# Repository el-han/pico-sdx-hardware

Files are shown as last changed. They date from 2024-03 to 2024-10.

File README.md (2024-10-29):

# Pico SDX

Pico SDX is a Software Defined HF Transceiver.

## Related Projects

- [uSDX](https://github.com/threeme3/usdx): ATmega 328P based SSB Transceiver. Large Arduino source file, no hardware sources, only schematics
- [(tr)uSDX](https://dl2man.de/): Implementation of uSDX by DL2MAN. No hardware sources, only schematics
- [uSDX-x](https://github.com/KD9PDP/uSDX-x): uSDX implementation with KiCAD hardware sources and JLCPCB friendly manufacturing data. ATmega328P based and compatible to uSDX. **Looks like a good starting point**
- [uSDR-pico](https://github.com/ArjanteMarvelde/uSDR-pico): RP2040 based SSB Transceiver. Highly experimental according to author. Pico SDK based Firmware, Eagle hardware sources. **Looks like a good starting point**
- [Blueberry SDR](http://www.andreadrian.de/sdr/Blueberry_SDR_schematics.html) experiments with different designs and components
- [YU1MLs SDRs](https://web.archive.org/web/20200227193146/http://yu1lm.qrpradio.com/sdr%20rx%20yu1lm.htm) many RX, TX and TRX designs
- [Teensy SDR](https://www.pjrc.com/convolution-software-defined-radio/) Teensy based sdr with waterfall diagram

## Related resources

- [Barbaros Aşuroğlu](https://antrak.org.tr/author/barbarosasuroglu/) has built an own uSDX implementation and many other projects.
- [QRP labs](https://www.qrp-labs.com/lpfkit.html) sells low pass and band pass filter modules for all HF bands
- [QRP labs](https://www.qrp-labs.com/synth/ms5351m.html) comparison between the clock generators Si5351A (Silicon labs) and MS5351M (Relmon) regarding usage in SDRs
- [Calculate your locator](https://dxcluster.ha8tks.hu/hamgeocoding/)

## technical background

- [Dan Tayloe](https://www.norcalqrp.org/files/Tayloe_mixer_x3a.pdf) brief description of the operation of quadratur mixers
- Gerald Youngbloods QEX articles [1](https://www.arrl.org/files/file/Technology/tis/info/pdf/020708qex013.pdf), [2](https://www.arrl.org/files/file/Technology/tis/info/pdf/020910qex010.pdf), [3](https://www.arrl.org/files/file/Technology/tis/info/pdf/021112qex027.pdf) and [4](http://www.arrl.org/files/file/Technology/tis/info/pdf/030304qex020.pdf) very good, detailed and comprehensive description of SDR projects for ham radio operators and additional [ARRL SDR](http://www.arrl.org/software-defined-radio) resources
- Walla Walla University projects: [Paper](http://fweb.wallawalla.edu/~frohro/ClassHandouts/Electronics/A%20Comparison%20of%20Affordable,%20Self-Assembled%20%20Software-Defined%20Radio%20Receivers%20Using%20Quadrature%20Sampling%20Down-Conversion.pdf), [Talk](https://www.youtube.com/watch?v=UoL1Qzaw2H0&t=217s),[Jordyn Watkins Wiki](https://github.com/greenjacketgirl/SDR_Receiver/wiki), [Caleb Froelichs Wiki](https://github.com/froeca/Software-Defined-Radio/), [Konrad MacClure](https://github.com/KonradMcClure/SDR_Receiver) and [SMD Version by Caleb Nelson](https://github.com/Dizzerin/Software-Defined-Radio)with detailed explanations, simulations, design decisions and tests
- [Burkhard Kainkas](https://www.b-kainka.de/iqrx.htm) experiments with iq mixers
- [devttys0](https://www.youtube.com/watch?v=JuuKF1RFvBM) video on explanations of the function of the tayloe mixer
- [w2aew](https://www.youtube.com/watch?v=Mm7WfVzr1ao) video on RF-mixer basics
- [BPF design for HF-Tranceiver](https://www.arrl.org/files/file/Technology/tis/info/pdf/8809017.pdf)
- [devttys0](https://www.youtube.com/watch?v=1sq8Cvju2Oo) video on practical filter design and construction

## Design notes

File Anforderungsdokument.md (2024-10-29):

Anforderungen Pico SDX
======================

Das soll es haben
-----------------

- Sendeleistung 20 W
- Betriebsarten:
    - SSB
    - WSPR
    - (CW)
- Bänder:
    - Kurzwelle
    - Unterstes Band: 80 Meter
    - Oberstes Band: 10 Meter
    - 4 bis 8 Bänder
- Stromversorgung:
    - Lithium-Akku (Rundzellen oder Modellbauakkus)
    - Ladeschaltung
    - USB-PD oder Rundstecker?
- Weitgehend tragbar (mindestens im Rucksack)
- Open Source Hardware, Firmware und Software
- PCB-Design in KiCAD

Damit würde ich beginnen, würde aber auch davon abweichen:
----------------------------------------------------------

- Microcontroller: RP2040
- Sprache:
    - Firmware: Micropython / Circuitpython
    - PC-Software: Python
- Antennenanschluss: BNC 50 Ohm
- Möglichst viele SMD-Komponenten / hybride Footprints
- Möglichst viele Komponenten aus dem  JLC Bestückungskatalog
- I2S Mikrophon und Lautsprecherverstärker
- Modularer Aufbau:
    - Stromversorgung
    - Filter
    - HF Platine
    - Digitalteil
    - Audioteil / PC-Verbindung
    - User Interface (Display, Schalter)

Offene Fragen:
--------------

* Gibt es gängige PC-Anwendungsschnittlstellen (USB-Soundkarte, UART-Protokoll, SDR-Treiber, ...)?
* Ist ein Wasserfalldiagramm umsetzbar?

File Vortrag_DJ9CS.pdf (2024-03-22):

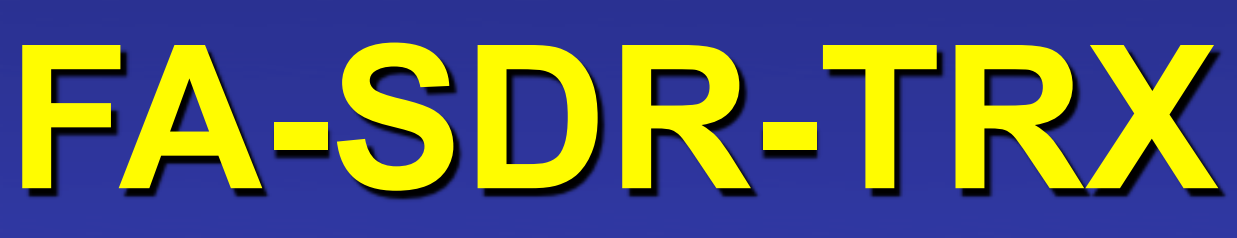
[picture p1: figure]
FA-SDR-TRX

## Einführung

## Software Defined Radio

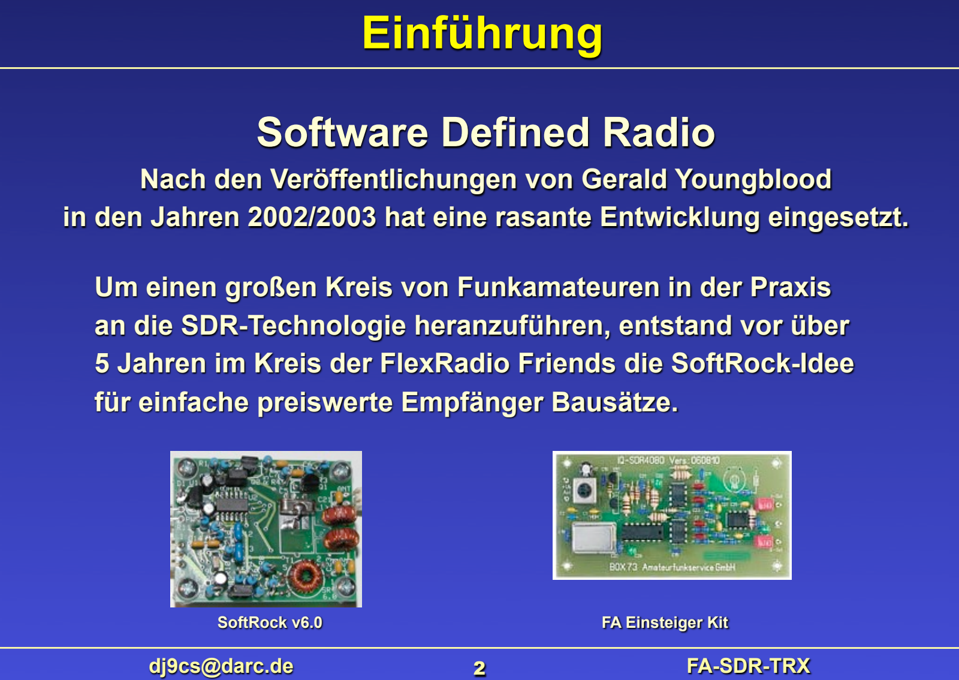
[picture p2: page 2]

dj9cs@darc.de | F 2 | A-SDR-TRX

Nach den Veröffentlichungen von Gerald Youngblood in den Jahren 2002/2003 hat eine rasante Entwicklung eingesetzt.

Um einen großen Kreis von Funkamateuren in der Praxis
an die SDR-Technologie heranzuführen, entstand vor über

### 5 Jahren im Kreis der FlexRadio Friends die SoftRock-Idee

für einfache preiswerte Empfänger Bausätze.

SoftRock v6.0 | FA Einsteiger Kit

## Einführung

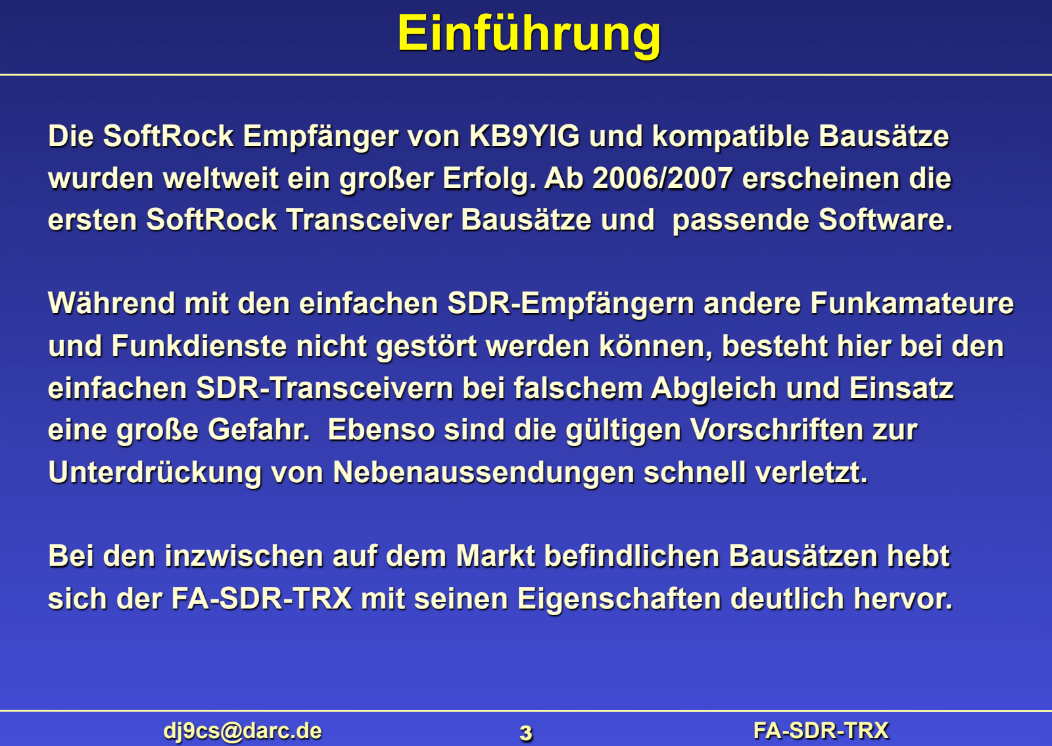
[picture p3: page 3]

dj9cs@darc.de | F 3 | A-SDR-TRX

Die SoftRock Empfänger von KB9YIG und kompatible Bausätze wurden weltweit ein großer Erfolg. Ab 2006/2007 erscheinen die ersten SoftRock Transceiver Bausätze und passende Software.

Während mit den einfachen SDR-Empfängern andere Funkamateure und Funkdienste nicht gestört werden können, besteht hier bei den einfachen SDR-Transceivern bei falschem Abgleich und Einsatz eine große Gefahr. Ebenso sind die gültigen Vorschriften zur Unterdrückung von Nebenaussendungen schnell verletzt.

Bei den inzwischen auf dem Markt befindlichen Bausätzen hebt sich der FA-SDR-TRX mit seinen Eigenschaften deutlich hervor.

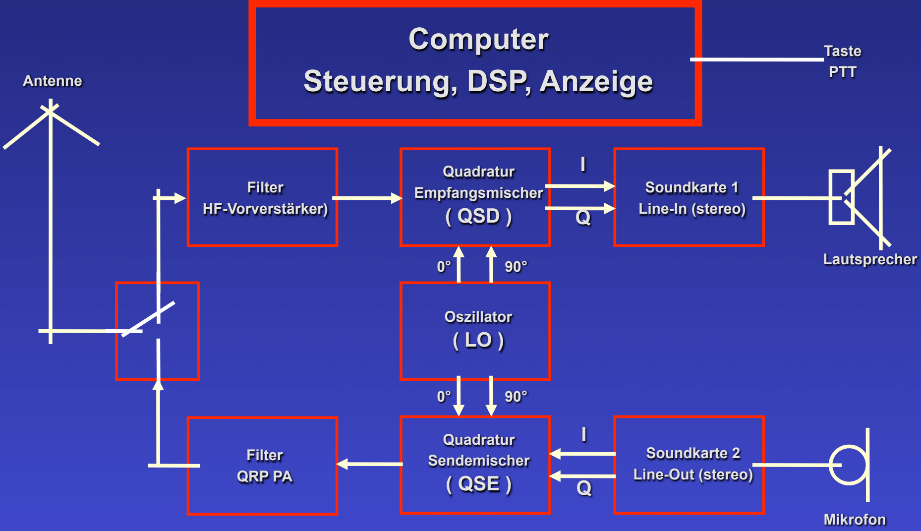
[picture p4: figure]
Computer Steuerung, DSP, Anzeige; Quadratur Empfangsmischer ( QSD ); Quadratur Sendemischer ( QSE ); Oszillator ( LO ); Soundkarte 1 Line-In (stereo); Soundkarte 2 Line-Out (stereo); Filter HF-Vorverstärker); Filter QRP PA; Mikrofon; Lautsprecher; Antenne; Taste PTT

dj9cs@darc.de | F 4 | A-SDR-TRX

dj9cs@darc.de | F 5 | A-SDR-TRX

Im Folgenden wird der FA-SDR-TRX mit seinen technischen Details dargestellt und aufgezeigt,

einem ausgezeichnetem Ergebnis geführt hat.

## Übersichtsschaltbild des FA- SDR-Transceivers

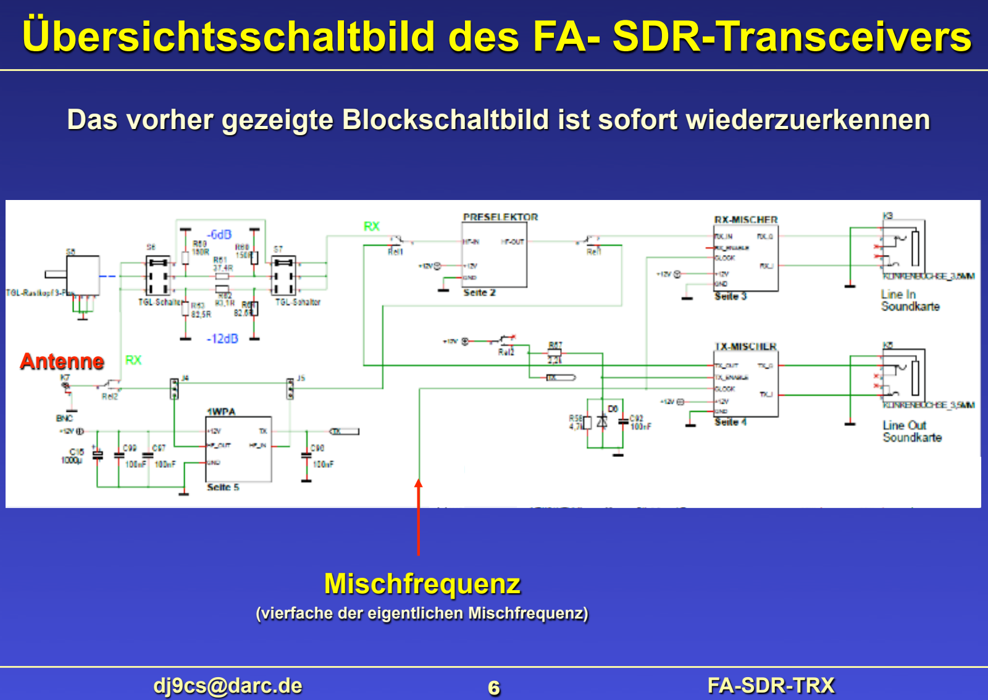
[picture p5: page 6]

dj9cs@darc.de | F 6 | A-SDR-TRX

Mischfrequenz

(vierfache der eigentlichen Mischfrequenz)

Antenne

Das vorher gezeigte Blockschaltbild ist sofort wiederzuerkennen

dj9cs@darc.de | F 7 | A-SDR-TRX

Den Kern der Osillatorbaugruppe bildet der Si570 von SiLabs. Es handelt sich um einen DSPLL-Chip mit herausragenden Eigenschaften. Bei DSPLL handelt es sich um ein Patent von Silicon Labs in den USA.
Mit dem Si570 werden Signale hoher Reinheit und Stabilität erzielt, vergleichbar mit Quarzoszillatoren.
Der Si570 stellt inzwischen einen Quasi-Standard bei allen SDR-Bausätzen dar. Hier im FA-SDR-TRX wird der FA-SY 1 eingesetzt.

## FA-SY im FA-SDR-TRX

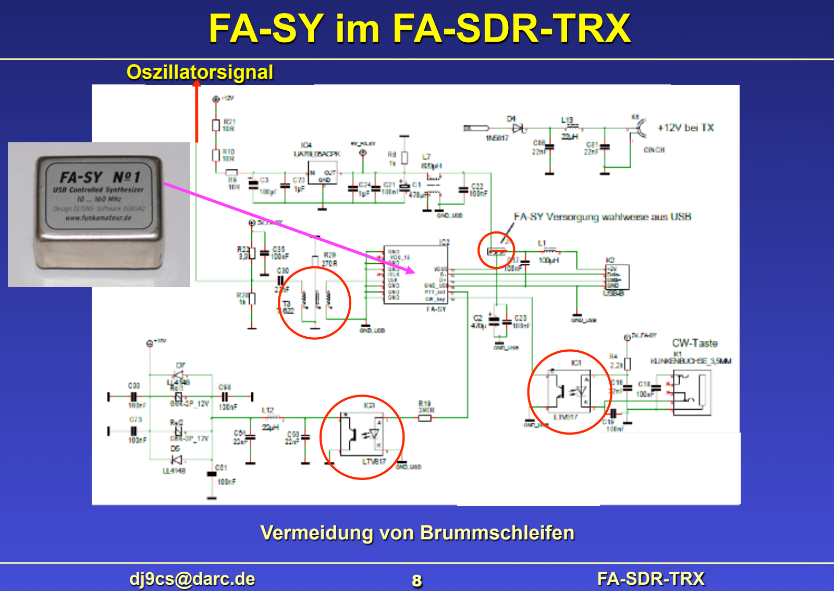
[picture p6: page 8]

dj9cs@darc.de | F 8 | A-SDR-TRX

Oszillatorsignal

Vermeidung von Brummschleifen

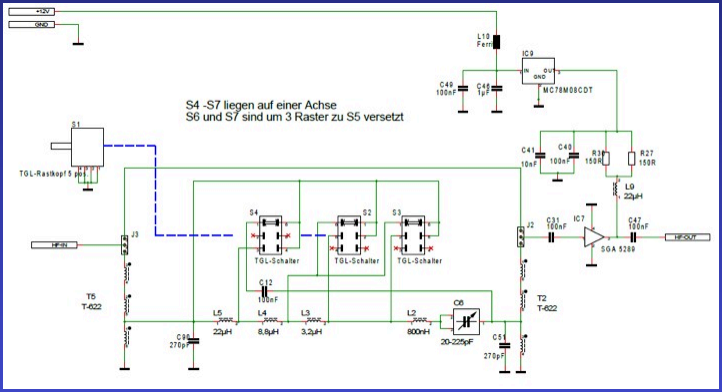
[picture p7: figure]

dj9cs@darc.de | F 9 | A-SDR-TRX

## Preselektor

dj9cs@darc.de | F 10 | A-SDR-TRX

Die Quadraturmischer im Empfänger und Sender sind die Kernbaugruppen im Konzept der einfachen SDR-Transceiver.

Die Empfängerdaten wie
- Empfindlichkeit (MDS @500Hz Bandbreite)
- Seitenbandunterdrückung
- nutzbarer Frequenzbereich
werden durch die Schaltkreise im Mischer wesentlich bestimmt. In
einem Experimentalaufbau wurden die Schalter-ICs FST3253, MAX4544, 74HC4066, MAX4614 und 74LVC4066 untersucht.
Mit den 74LVC4066 werden die besten Ergebnisse erreicht. Bis ins 2m-Band sind sie bei Subharmonischenmischung einsetzbar. Eine geringe Streuung in den Daten erlaubt zudem eine hohe Nachbausicherheit.

## Empfängermischer (QSD)

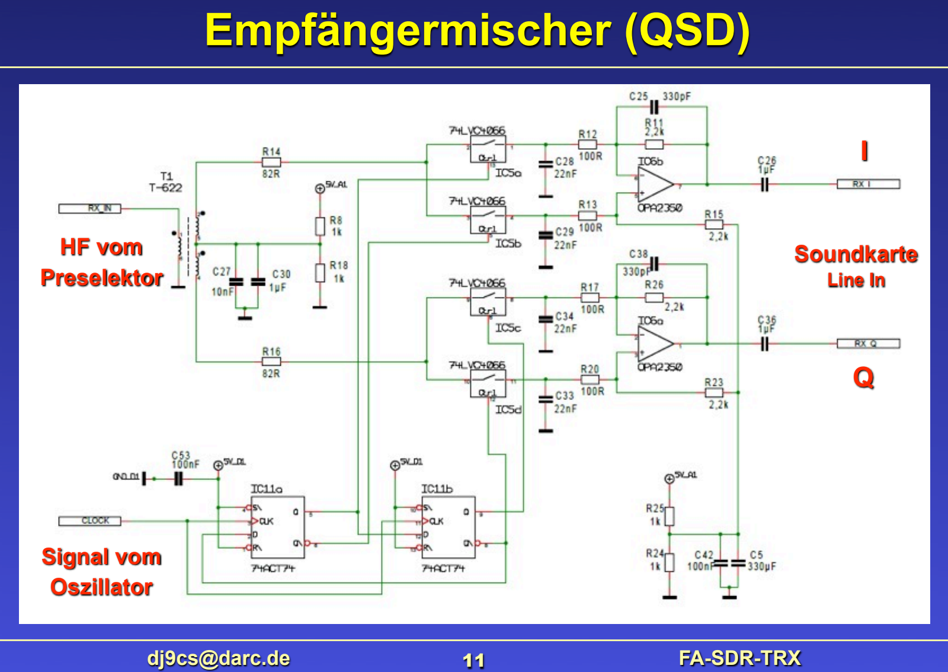
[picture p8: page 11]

dj9cs@darc.de | F 11 | A-SDR-TRX

I

Q

Soundkarte
Line In

HF vom
Preselektor

Signal vom
Oszillator

## Empfängermischer

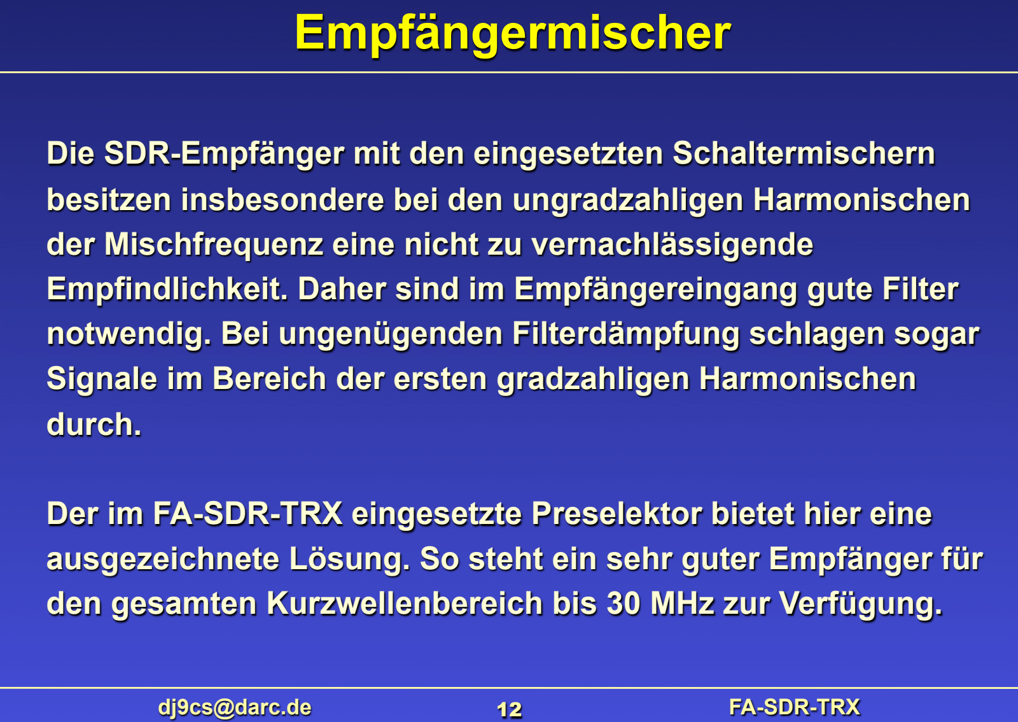
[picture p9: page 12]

dj9cs@darc.de | F 12 | A-SDR-TRX

Die SDR-Empfänger mit den eingesetzten Schaltermischern besitzen insbesondere bei den ungradzahligen Harmonischen der Mischfrequenz eine nicht zu vernachlässigende Empfindlichkeit. Daher sind im Empfängereingang gute Filter notwendig. Bei ungenügenden Filterdämpfung schlagen sogar Signale im Bereich der ersten gradzahligen Harmonischen durch.

Der im FA-SDR-TRX eingesetzte Preselektor bietet hier eine ausgezeichnete Lösung. So steht ein sehr guter Empfänger für den gesamten Kurzwellenbereich bis 30 MHz zur Verfügung.

dj9cs@darc.de | F 13 | A-SDR-TRX

Für den Sendebetrieb werden die I/Q-Signale im PC in der DSP berechnet und über die Soundkarte als analoge Signale dem Sendermischer zugeführt.

## Sendermischer (QSE)

dj9cs@darc.de | F 14 | A-SDR-TRX

Soundkarte
Line Out

I

Q

QRP PA
über
Filter

Signal vom
Oszillator

Trägerunterdrückung

Spiegelfrequenzunterdrückung

## Sendermischer

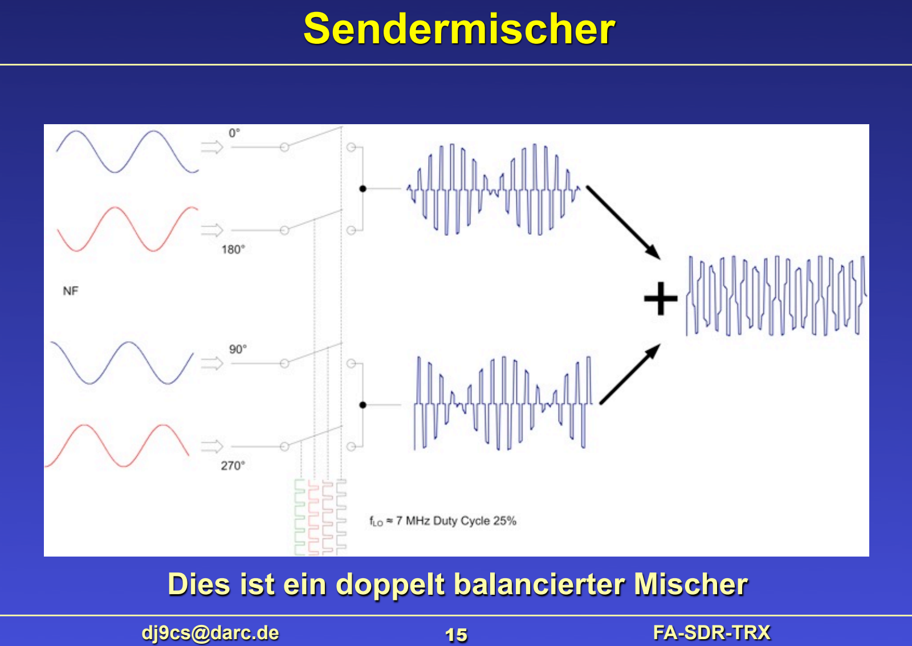
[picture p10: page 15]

dj9cs@darc.de | F 15 | A-SDR-TRX

Dies ist ein doppelt balancierter Mischer

## Sendermischer

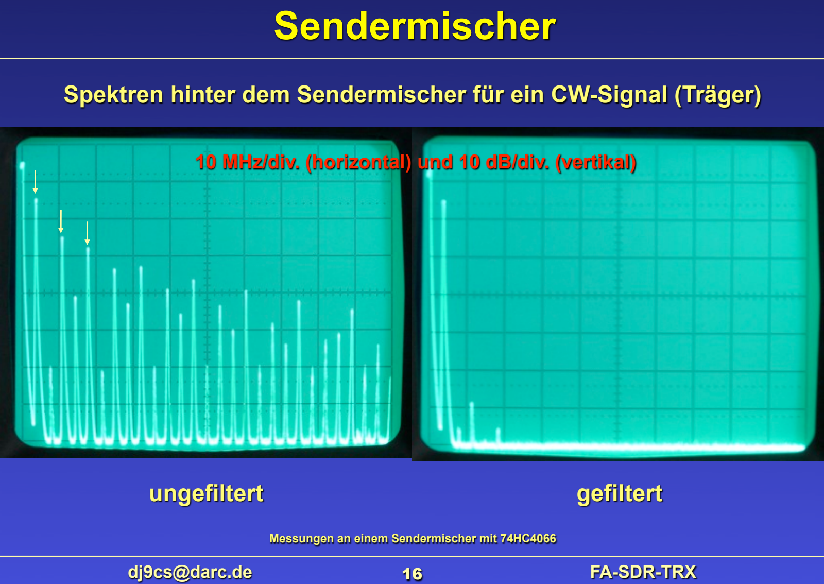
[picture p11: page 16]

dj9cs@darc.de | F 16 | A-SDR-TRX

Spektren hinter dem Sendermischer für ein CW-Signal (Träger)

### 10 MHz/div. (horizontal) und 10 dB/div. (vertikal)

ungefiltert | gefiltert

Messungen an einem Sendermischer mit 74HC4066

dj9cs@darc.de | F 17 | A-SDR-TRX

Die Messungen am AVALA-01 Transceiver haben die Bedeutung eines Filters direkt hinter dem Sendemischer gezeigt. Das breite Ausgangsspektrum und unvermeidbare Nichtlinearitäten der folgenden Stufen von Treiber und PA führen ganz schnell zu unerwünschten Signalen am Ausgang des Senders. Die Vorschriften zu Nebenaussendungen (Verfügung Nr. 33/2007) sind so kaum einzuhalten.

Im FA-SDR-TRX wird im Sendezweig der Preselektor mitgenutzt, eine optimale Lösung in diesem Zusammenhang.

Die Grundausgangsleistung hinter dem Preselektor mit dem SGA5289 beträgt 10mW. Mit dieser Leistung kann die 5Watt QRP PA von Harald DL2EWN ausgesteuert werden.

## Übersichtsschaltbild des FA- SDR-Transceivers

dj9cs@darc.de | F 18 | A-SDR-TRX

## 1 Watt QRP PA als Steckmodul

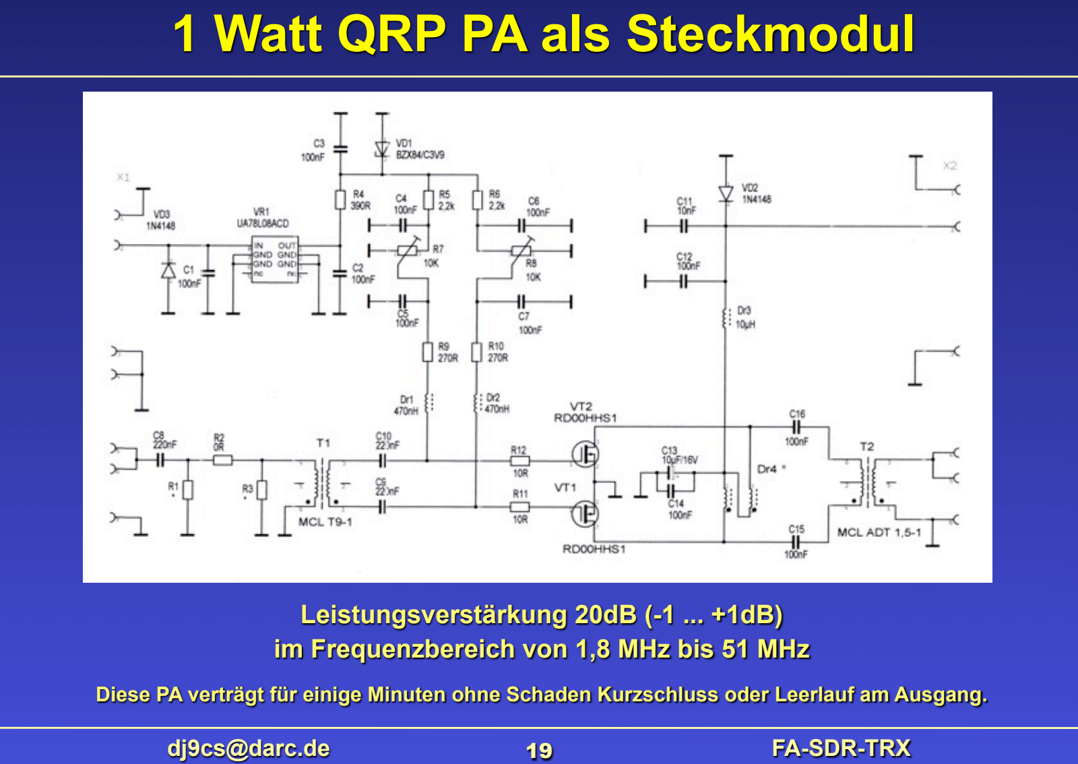
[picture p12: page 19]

dj9cs@darc.de | F 19 | A-SDR-TRX

Leistungsverstärkung 20dB (-1 ... +1dB) im Frequenzbereich von 1,8 MHz bis 51 MHz

Diese PA verträgt für einige Minuten ohne Schaden Kurzschluss oder Leerlauf am Ausgang.

## Der Bausatz FA-SDR-TRX

dj9cs@darc.de | F 20 | A-SDR-TRX

Der Aufbau des FA-SDR-TRX stellt keine wirkliche Herausforderung dar. In bewährter Weise wird die Platine (163 mm * 114 mmm) mit allen SMD-Bauteilen bestückt geliefert. Es verbleiben wenige konventionelle Bauteile.

Die Oszillatorbaugruppe mit dem Si570 ‘FA-SY-01‘ wird auf die Platine gesteckt, ebenso der optionale kleine Breitbandverstärker mit 1 Watt Ausgangsleistung.

Ein passendes Gehäuse mit den notwendigen Bohrungen und Beschriftungen ergibt dann einen auch optisch schönen
SDR Kurzwellen QRP-Transceiver.

## Der aufgebaute FA-SDR-TRX

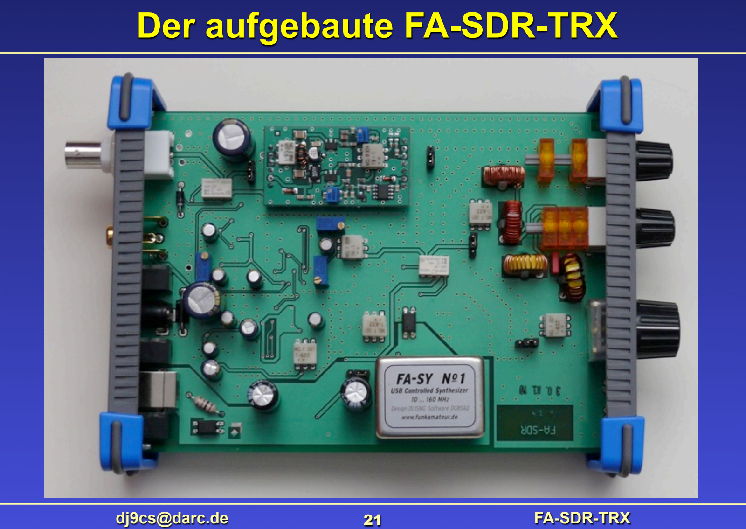
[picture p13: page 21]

dj9cs@darc.de | F 21 | A-SDR-TRX

## Betriebsbereiter FA-SDR-TRX

dj9cs@darc.de | F 22 | A-SDR-TRX

## Betrieb des FA-SDR-TRX als Empfänger

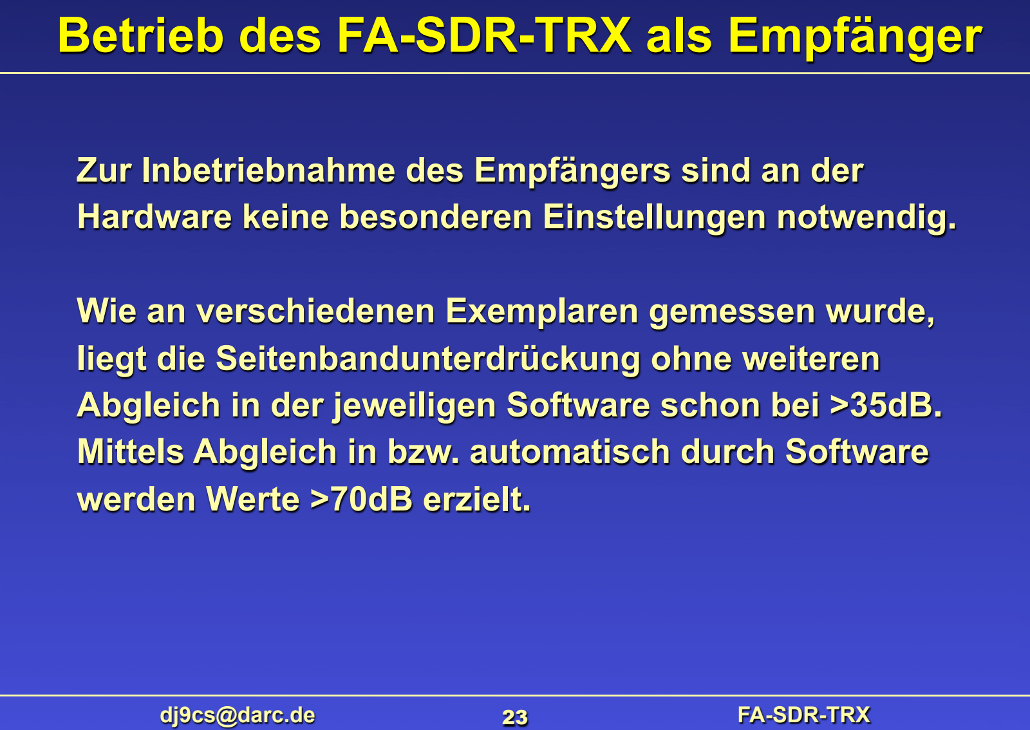
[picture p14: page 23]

dj9cs@darc.de | F 23 | A-SDR-TRX

Zur Inbetriebnahme des Empfängers sind an der Hardware keine besonderen Einstellungen notwendig.

Wie an verschiedenen Exemplaren gemessen wurde, liegt die Seitenbandunterdrückung ohne weiteren Abgleich in der jeweiligen Software schon bei >35dB. Mittels Abgleich in bzw. automatisch durch Software werden Werte >70dB erzielt.

## Betrieb des FA-SDR-TRX als Empfänger

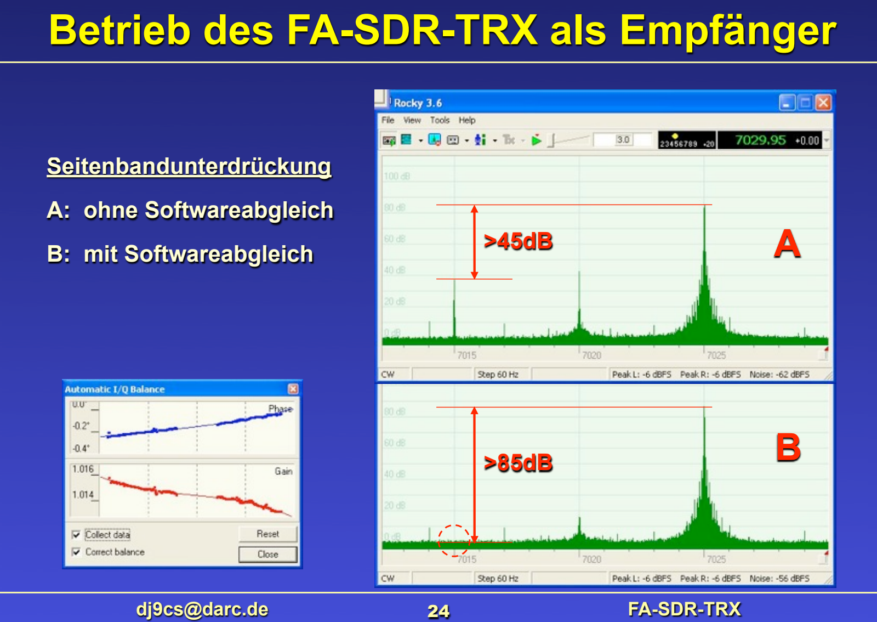
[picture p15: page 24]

dj9cs@darc.de | F 24 | A-SDR-TRX

Seitenbandunterdrückung
A: ohne Softwareabgleich
B: mit Softwareabgleich | A

B

>45dB

>85dB

## Intermodulationsmessung am Empfänger

dj9cs@darc.de | F 25 | A-SDR-TRX

Pegel am Ausgang des Combiners ca. 0 dBm

Messaufbau mit zwei Signalgeneratoren mit dem Si570 Aufbau und Firmware nach Kees, K5BCQ

## Intermodulationsmessung am Empfänger

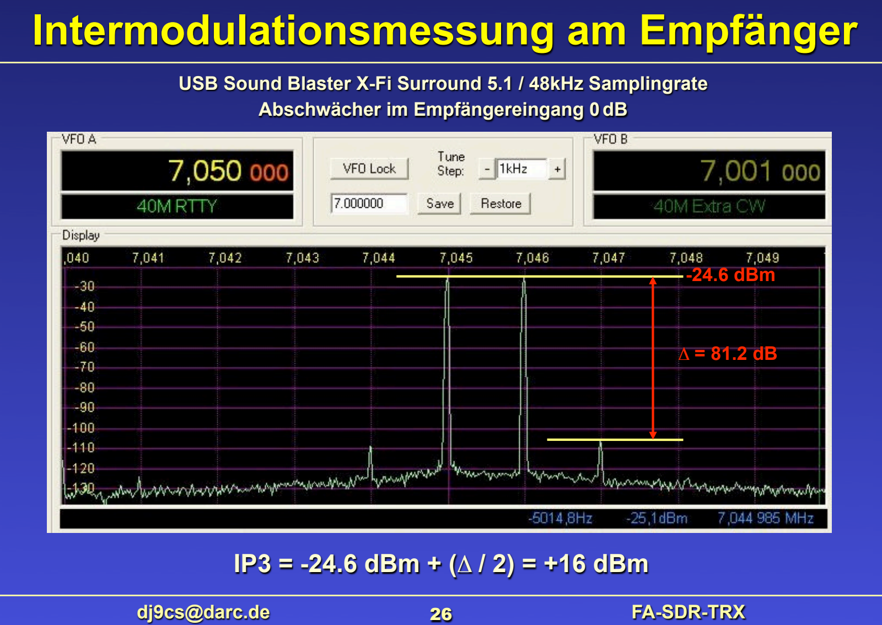
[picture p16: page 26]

dj9cs@darc.de | F 26 | A-SDR-TRX

-24.6 dBm

Δ = 81.2 dB

IP3 = -24.6 dBm + (Δ / 2) = +16 dBm

USB Sound Blaster X-Fi Surround 5.1 / 48kHz Samplingrate Abschwächer im Empfängereingang 0 dB

## Daten des Empfängers im FA-SDR-TRX

dj9cs@darc.de | F 27 | A-SDR-TRX
Frequenzbereich Rx/Tx | 1,7 MHz bis 30 MHz
Die Empfängereigenschaften sind stark abhängig von der eingesetzten Soundkarte. Mit der sehr guten USB-Karte E-MU0202 USB, die bei

### 24 bit Auflösung bis 192 kHz Abtastrate bietet, werden folgende Werte

erreicht:
Empfindlichkeit bei 48 kHz Abtastrate (MDS @500Hz Bandbreite)
80m Band: | -133 dBm
20m Band: | -137 dBm
IP3 am Rx Eingang | > +15 dBm
Intermodulationsfreier Dynamikbereich IMDR3 | > 90 dB

Mit der CREATIVE USB Sound Blaster X-Fi Surround 5.1 konnte ich die obigen Werte auch fast erreichen.

## Betrieb des FA-SDR-TRX als Empfänger

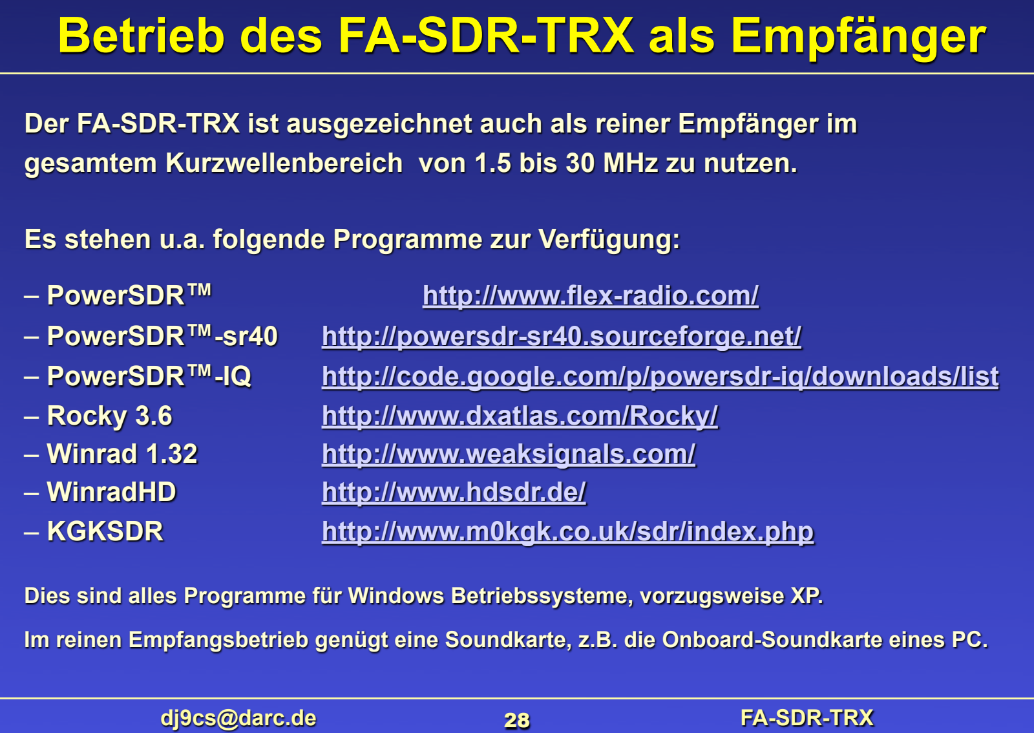
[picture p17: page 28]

dj9cs@darc.de | F 28 | A-SDR-TRX

Der FA-SDR-TRX ist ausgezeichnet auch als reiner Empfänger im gesamtem Kurzwellenbereich von 1.5 bis 30 MHz zu nutzen.

Es stehen u.a. folgende Programme zur Verfügung:

– PowerSDR™ | http://www.flex-radio.com/
– PowerSDR™-sr40 | http://powersdr-sr40.sourceforge.net/
– PowerSDR™-IQ | http://code.google.com/p/powersdr-iq/downloads/list
– Rocky 3.6 | http://www.dxatlas.com/Rocky/
– Winrad 1.32 | http://www.weaksignals.com/
– WinradHD | http://www.hdsdr.de/
– KGKSDR | http://www.m0kgk.co.uk/sdr/index.php

Dies sind alles Programme für Windows Betriebssysteme, vorzugsweise XP.

Im reinen Empfangsbetrieb genügt eine Soundkarte, z.B. die Onboard-Soundkarte eines PC.

## FA-SDR-TRX als Empfänger

dj9cs@darc.de | F 29 | A-SDR-TRX

WinradHD mit einer Onboard-Soundkarte

LENOVO Netbook S10-2 mit Realtek Soundkarte

## Transceiverbetrieb

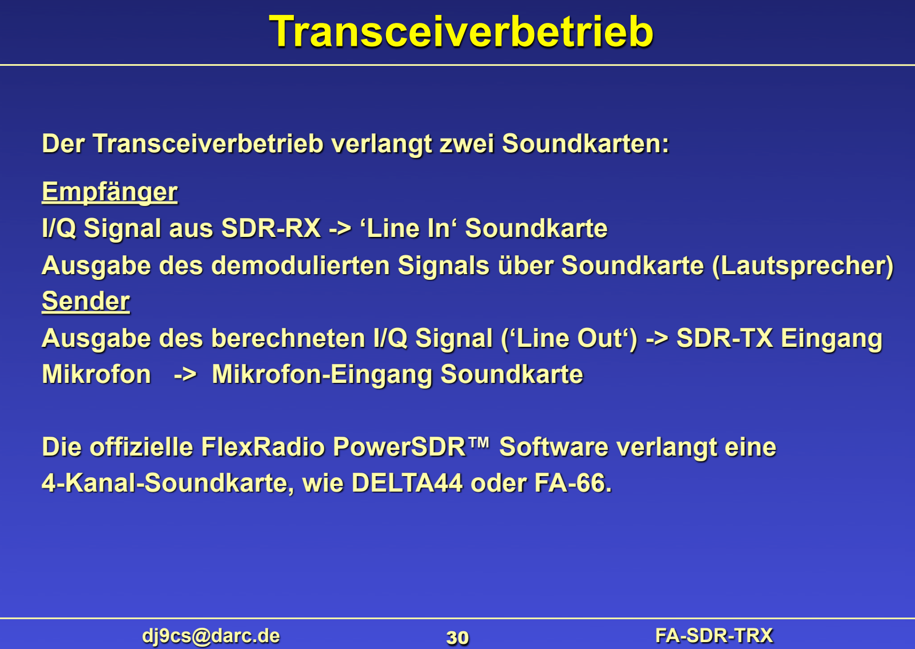
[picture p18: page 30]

dj9cs@darc.de | F 30 | A-SDR-TRX

Der Transceiverbetrieb verlangt zwei Soundkarten:
Empfänger
I/Q Signal aus SDR-RX -> ‘Line In‘ Soundkarte
Ausgabe des demodulierten Signals über Soundkarte (Lautsprecher) Sender
Ausgabe des berechneten I/Q Signal (‘Line Out‘) -> SDR-TX Eingang Mikrofon -> Mikrofon-Eingang Soundkarte

Die offizielle FlexRadio PowerSDR™ Software verlangt eine 4-Kanal-Soundkarte, wie DELTA44 oder FA-66.

dj9cs@darc.de | F 31 | A-SDR-TRX

Für diese Konfiguration stehen folgende Programme zur Verfügung:

- Rocky 3.6 | http://www.dxatlas.com/Rocky/
- PowerSDR™-sr40 http://powersdr-sr40.sourceforge.net/
- PowerSDR™-IQ http://code.google.com/p/powersdr-iq/downloads/list

## Rocky 3.6

dj9cs@darc.de | F 32 | A-SDR-TRX
Setup: | Soundkarte SB Live! 24-bit External Realtek HD Audio output (onboard) Si570 USB Multiband

## Rocky 3.6

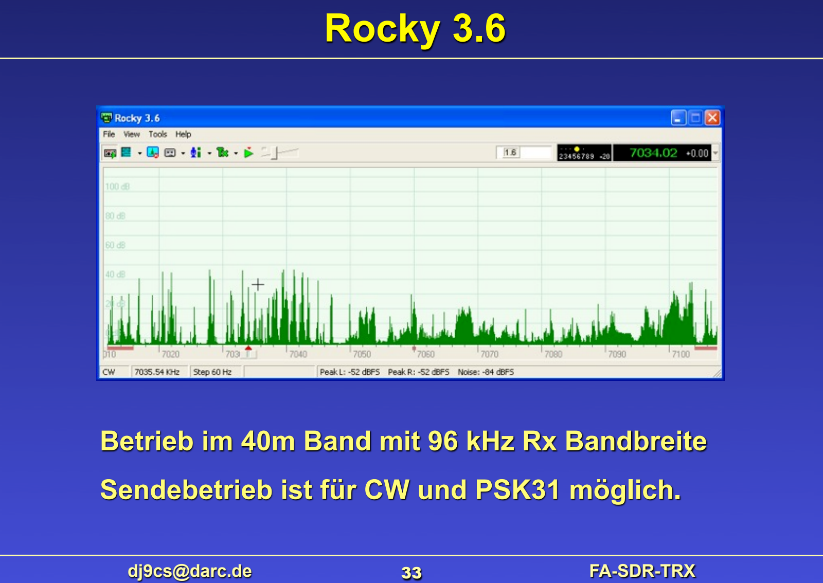
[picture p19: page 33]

dj9cs@darc.de | F 33 | A-SDR-TRX

Betrieb im 40m Band mit 96 kHz Rx Bandbreite Sendebetrieb ist für CW und PSK31 möglich.

dj9cs@darc.de | F 34 | A-SDR-TRX

## Rocky 3.6

PSK31 Betrieb | empfangener Text

dj9cs@darc.de | F 35 | A-SDR-TRX

Aufgrund des Engagements einiger OMs ist es möglich den FA-SDR-TRX wie einen SDR-1000 Tansceiver von FlexRadio zu betreiben. Der Dank geht insbesondere an Guido PE1NNZ für die Version ‘PowerSDR-sr40‘, an Christos SV1EIA für die Version ‘PowerSDR-IQ‘ und an Fred PE0FKO für die Firmware im AVR und zugehörigem

## PowerSDR-sr40 Setup

dj9cs@darc.de | F 36 | A-SDR-TRX

## Betrieb des FA-SDR-TRX

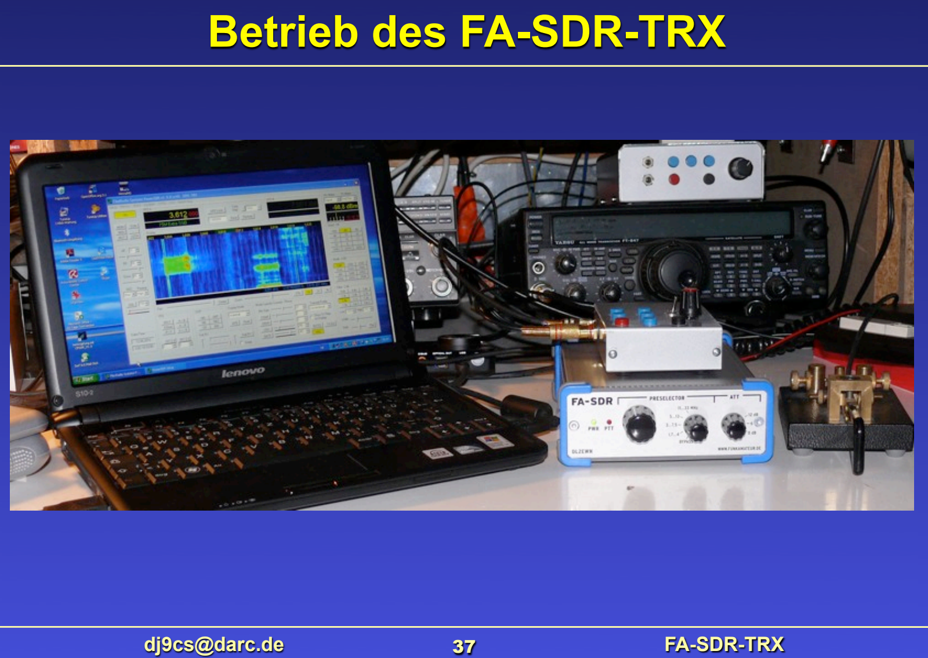
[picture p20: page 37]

dj9cs@darc.de | F 37 | A-SDR-TRX

## Betrieb des FA-SDR-TRX als SDR-1000

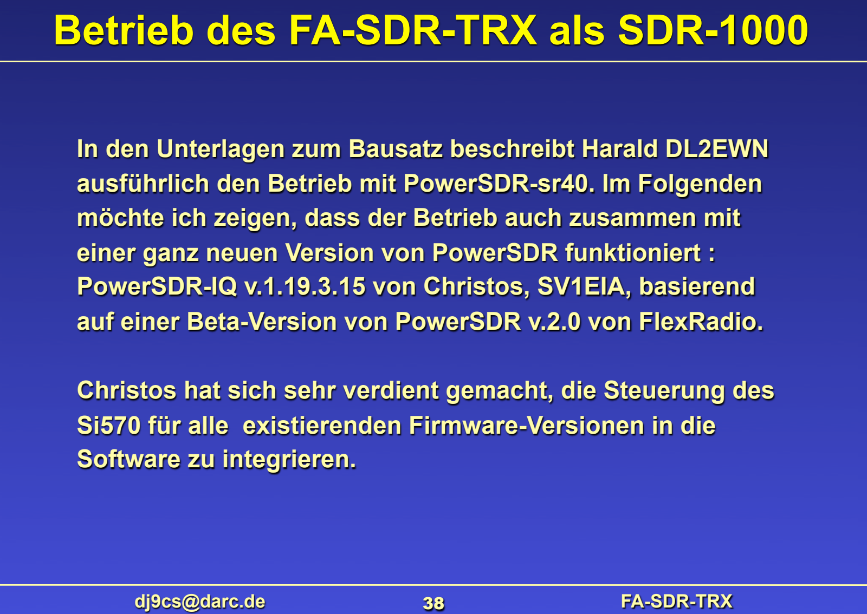
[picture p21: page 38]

dj9cs@darc.de | F 38 | A-SDR-TRX

In den Unterlagen zum Bausatz beschreibt Harald DL2EWN ausführlich den Betrieb mit PowerSDR-sr40. Im Folgenden möchte ich zeigen, dass der Betrieb auch zusammen mit einer ganz neuen Version von PowerSDR funktioniert : PowerSDR-IQ v.1.19.3.15 von Christos, SV1EIA, basierend auf einer Beta-Version von PowerSDR v.2.0 von FlexRadio.

Christos hat sich sehr verdient gemacht, die Steuerung des Si570 für alle existierenden Firmware-Versionen in die Software zu integrieren.

## PowerSDR-IQ v.1.19.3.15

dj9cs@darc.de | F 39 | A-SDR-TRX

SSB Betrieb

## PowerSDR-IQ v.1.19.3.15

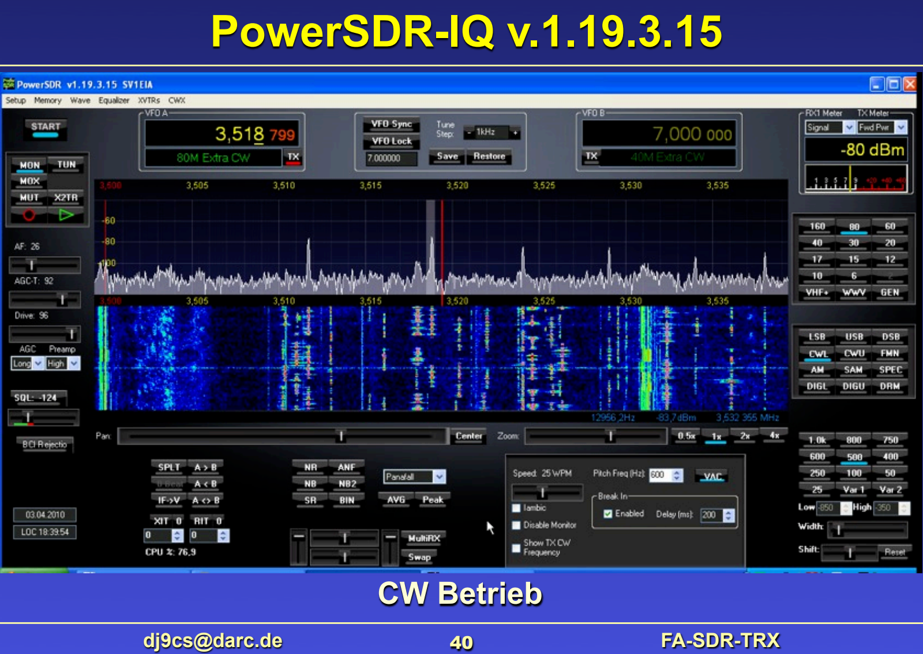
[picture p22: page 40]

dj9cs@darc.de | F 40 | A-SDR-TRX

CW Betrieb

dj9cs@darc.de | F 41 | A-SDR-TRX

## Intermodulationsmessung am Sender

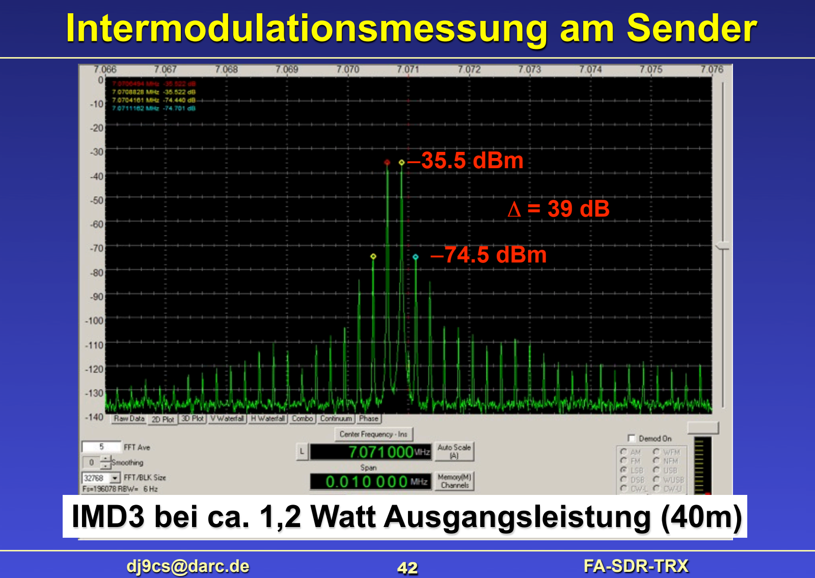
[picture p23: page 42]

dj9cs@darc.de | F 42 | A-SDR-TRX

–35.5 dBm

–74.5 dBm

Δ = 39 dB

## IMD3 bei ca. 1,2 Watt Ausgangsleistung (40m)

dj9cs@darc.de | F 43 | A-SDR-TRX

Die Senderausgangsleistung beträgt im gesamten Frequenzbereich bis 30 MHz 10 mW PEP bzw. 1 Watt PEP mit der kleinen Breitbandendstufe.

Die herausragende Linearität wird bezeugt durch die Messwerte zum Abstand der Intermodulationsprodukte.

So werden auf 40m erreicht
PIM3 = -55 dBc (-61dB PEP) bei 10mW ohne 1 Watt Breitbandendstufe

PIM3 = -40 dBc (-46dB PEP) bei 1 Watt aus der Breitbandendstufe

## Anmerkung zum Betrieb des Senders

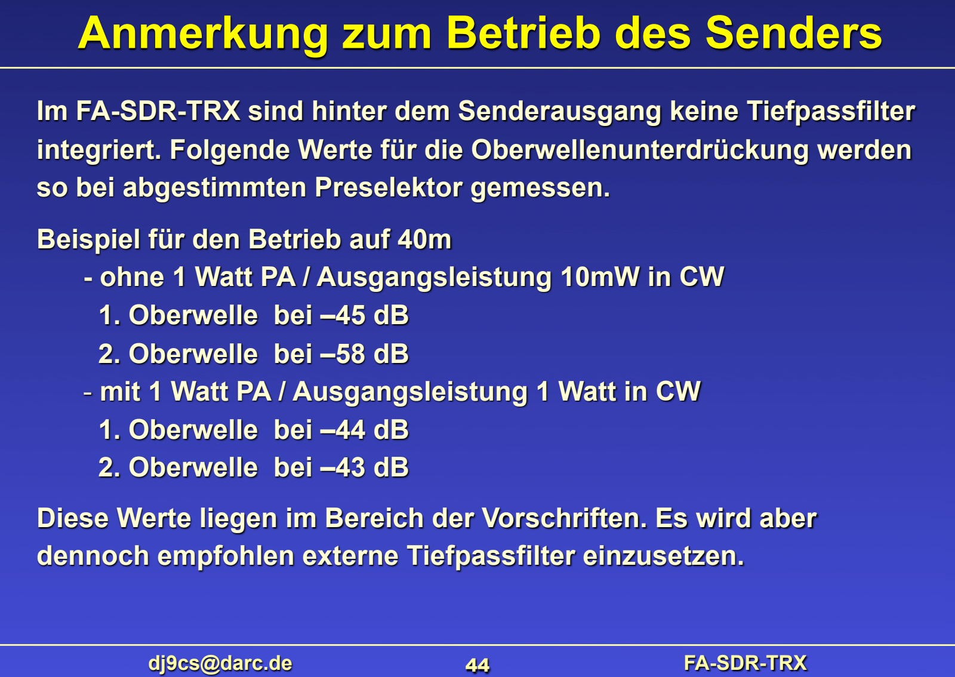
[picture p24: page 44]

dj9cs@darc.de | F 44 | A-SDR-TRX

Im FA-SDR-TRX sind hinter dem Senderausgang keine Tiefpassfilter integriert. Folgende Werte für die Oberwellenunterdrückung werden so bei abgestimmten Preselektor gemessen.
Beispiel für den Betrieb auf 40m
- ohne 1 Watt PA / Ausgangsleistung 10mW in CW

### 1. Oberwelle bei –45 dB 2. Oberwelle bei –58 dB

- mit 1 Watt PA / Ausgangsleistung 1 Watt in CW

### 1. Oberwelle bei –44 dB 2. Oberwelle bei –43 dB

Diese Werte liegen im Bereich der Vorschriften. Es wird aber dennoch empfohlen externe Tiefpassfilter einzusetzen.

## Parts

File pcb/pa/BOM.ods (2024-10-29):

Part | Value | Description | Package | Library | Manu | Part No. | Vendor | Part No.
J1 | 3 Pin | 0.1 in sq, polarized | MA03-1 | 0G_Connectors | Molex | 22-11-2032 | Mouser | 538-22-11-2032
J2 | Pwr Conn | KK-MAXI-2 HORIZ | KK-MAXI-2H | 0G_DDS-Controller | Molex | 26-60-5020 | Mouser | 538-26-60-5020
R06 | 0 | Chip Res R1206 | R1206 | 0G_RCL | Xicon | 263-0-RC | Mouser | 263-0-RC
R10 | 0 | Chip Res R1206 | R1206 | 0G_RCL | Xicon | 263-0-RC | Mouser | 263-0-RC
R01 | 1 | Chip Res R1206 | R1206 | 0G_RCL | Xicon | 263-1-RC | Mouser | 263-1-RC
R13 | 1 | Chip Res R1206 | R1206 | 0G_RCL | Xicon | 263-1-RC | Mouser | 263-1-RC
R19 | 10K | Chip Res R1206 | R1206 | 0G_RCL | Xicon | 263-10K-RC | Mouser | 263-10K-RC
R14 | 1K | Chip Res R1206 | R1206 | 0G_RCL | Xicon | 263-1K-RC | Mouser | 263-1K-RC
R18 | 1K | Chip Res R1206 | R1206 | 0G_RCL | Xicon | 263-1K-RC | Mouser | 263-1K-RC
R03 | 56 | Chip Res R1206 | R1206 | 0G_RCL | Xicon | 263-56-RC | Mouser | 263-56-RC
R04 | 56 | Chip Res R1206 | R1206 | 0G_RCL | Xicon | 263-56-RC | Mouser | 263-56-RC
R15 | 56 | Chip Res R1206 | R1206 | 0G_RCL | Xicon | 263-56-RC | Mouser | 263-56-RC
R16 | 56 | Chip Res R1206 | R1206 | 0G_RCL | Xicon | 263-56-RC | Mouser | 263-56-RC
R11 | 2K | TRIMPOT | 3362P | 0G_Passives | Bourns | 3362P-1-202LF | Mouser | 652-3362P-1-202LF
R17 | 2K | TRIMPOT | 3362P | 0G_Passives | Bourns | 3362P-1-202LF | Mouser | 652-3362P-1-202LF
X1 | BNC | Right Angle Jack | SD-73100 | 0G_Connectors | Molex | 73100-0105 | Mouser | 538-73100-0105
X2 | BNC | Right Angle Jack | SD-73100 | 0G_Connectors | Molex | 73100-0105 | Mouser | 538-73100-0105
C02 | 1000uF | CPOL-USH | PANASONIC_H | 0G_RCL | Cornell Dubilier | AFK108M25H32T-F | Mouser | 5985-AFK25V1000-F
T2 | BN-43-202 | Ferrite Xmfr | BN302-1W1T | 0G_RF_Magnetics | FairRite | BN-43-202 | Amidon | BN-43-202
T1 | BN-43-302 | Ferrite Xmfr | BN302-2W2T-H | 0G_RF_Magnetics | FairRite | BN-43-302 | Amidon | BN-43-302
C07 | 0.01 uF | Chip Cap C1206 | C1206 | 0G_RCL | Kemet | C1206C103K3RACTU | Mouser | 80-C1206C103K3R
C10 | 0.01 uF | Chip Cap C1206 | C1206 | 0G_RCL | Kemet | C1206C103K3RACTU | Mouser | 80-C1206C103K3R
C12 | 0.01 uF | Chip Cap C1206 | C1206 | 0G_RCL | Kemet | C1206C103K3RACTU | Mouser | 80-C1206C103K3R
C18 | 0.01 uF | Chip Cap C1206 | C1206 | 0G_RCL | Kemet | C1206C103K3RACTU | Mouser | 80-C1206C103K3R
C01 | 0.1uF | Chip Cap C1206 | C1206 | 0G_RCL | Kemet | C1206C104K3RACTU | Mouser | 80-C1206C104K3R
C03 | 0.1uF | Chip Cap C1206 | C1206 | 0G_RCL | Kemet | C1206C104K3RACTU | Mouser | 80-C1206C104K3R
C04 | 0.1uF | Chip Cap C1206 | C1206 | 0G_RCL | Kemet | C1206C104K3RACTU | Mouser | 80-C1206C104K3R
C05 | 0.1uF | Chip Cap C1206 | C1206 | 0G_RCL | Kemet | C1206C104K3RACTU | Mouser | 80-C1206C104K3R
C06 | 0.1uF | Chip Cap C1206 | C1206 | 0G_RCL | Kemet | C1206C104K3RACTU | Mouser | 80-C1206C104K3R
C08 | 0.1uF | Chip Cap C1206 | C1206 | 0G_RCL | Kemet | C1206C104K3RACTU | Mouser | 80-C1206C104K3R
C09 | 0.1uF | Chip Cap C1206 | C1206 | 0G_RCL | Kemet | C1206C104K3RACTU | Mouser | 80-C1206C104K3R
C13 | 0.1uF | Chip Cap C1206 | C1206 | 0G_RCL | Kemet | C1206C104K3RACTU | Mouser | 80-C1206C104K3R
C14 | 0.1uF | Chip Cap C1206 | C1206 | 0G_RCL | Kemet | C1206C104K3RACTU | Mouser | 80-C1206C104K3R
C15 | 0.1uF | Chip Cap C1206 | C1206 | 0G_RCL | Kemet | C1206C104K3RACTU | Mouser | 80-C1206C104K3R
C16 | 0.1uF | Chip Cap C1206 | C1206 | 0G_RCL | Kemet | C1206C104K3RACTU | Mouser | 80-C1206C104K3R
C17 | 0.1uF | Chip Cap C1206 | C1206 | 0G_RCL | Kemet | C1206C104K3RACTU | Mouser | 80-C1206C104K3R
C19 | 0.1uF | Chip Cap C1206 | C1206 | 0G_RCL | Kemet | C1206C104K3RACTU | Mouser | 80-C1206C104K3R
C21 | 0.1uF | Chip Cap C1206 | C1206 | 0G_RCL | Kemet | C1206C104K3RACTU | Mouser | 80-C1206C104K3R
C22 | 0.1uF | Chip Cap C1206 | C1206 | 0G_RCL | Kemet | C1206C104K3RACTU | Mouser | 80-C1206C104K3R
C23 | 0.1uF | Chip Cap C1206 | C1206 | 0G_RCL | Kemet | C1206C104K3RACTU | Mouser | 80-C1206C104K3R
C24 | 0.1uF | Chip Cap C1206 | C1206 | 0G_RCL | Kemet | C1206C104K3RACTU | Mouser | 80-C1206C104K3R
C26 | 0.1uF | Chip Cap C1206 | C1206 | 0G_RCL | Kemet | C1206C104K3RACTU | Mouser | 80-C1206C104K3R
C20 | 1 uF | Chip Cap C1206 | C1206 | 0G_RCL | Kemet | C1206C105K3RACTU | Mouser | 80-C1206C105K3R
C25 | 100uF | CPOL-USF | PANASONIC_F | 0G_RCL | United CC | EMKA250ADA101MHA0G | Mouser | 661-MKA25VC101M
L3 | FB-73-101 | Ferrite bead | LP-CHOKE | 0G_RF_Magnetics | FairRite | FB-73-101 | Amidon | FB-73-101
L4 | FB-73-101 | Ferrite bead | LP-CHOKE | 0G_RF_Magnetics | FairRite | FB-73-101 | Amidon | FB-73-101
L1 | FB-73-801 | Ferrite bead | HP-CHOKE | 0G_RF_Magnetics | FairRite | FB-73-801 | Amidon | FB-73-801
L2 | FB-73-801 | Ferrite bead | HP-CHOKE | 0G_RF_Magnetics | FairRite | FB-73-801 | Amidon | FB-73-801
U1 | 6V Reg | L78L06_D | SO08 | 0G_Regulators | STM | L78L06ACD13TR | Mouser | 511-L78L06ACD-TR
Q1 | RD15VHF1 | RF LDMOS FET | TO220HOLE | 0G_Mitubishi RF Power | Mitubishi | RD15VHF1 | RFParts | RD15VHF1
Q2 | RD15VHF1 | RF LDMOS FET | TO220HOLE | 0G_Mitubishi RF Power | Mitubishi | RD15VHF1 | RFParts | RD15VHF1
T3 | RF-800-4 | Ferrite Xmfr | RF-800 | 0G_RF_Magnetics | CCI | RF-800-4 | CCI | RF-800-4
C11B | 330pF | Chip Cap C1210 | C1210 | 0G_Passives | AVX | SQCB2M331JAJME | Digikey | 478-2660-1-ND
C11A | 180pF | Chip Cap C1210 | C1210 | 0G_Passives | AVX | SQCB9M181JAJME | Digikey | 478-2654-1-ND
Q3 | ZVP2106G | P-Chnl MOSFET | SOT223 | 0G_Regulators | Zetex | ZVP2106GTA | Mouser | 522-ZVP2106GTA
R02 | NP | Chip Res R1206 | R1206 | 0G_RCL
R05 | NP | Chip Res R1206 | R1206 | 0G_RCL
R07 | NP | Chip Res R1206 | R1206 | 0G_RCL
R08 | NP | Chip Res R1206 | R1206 | 0G_RCL
R09 | NP | Chip Res R1206 | R1206 | 0G_RCL
R12 | NP | Chip Res R1206 | R1206 | 0G_RCL

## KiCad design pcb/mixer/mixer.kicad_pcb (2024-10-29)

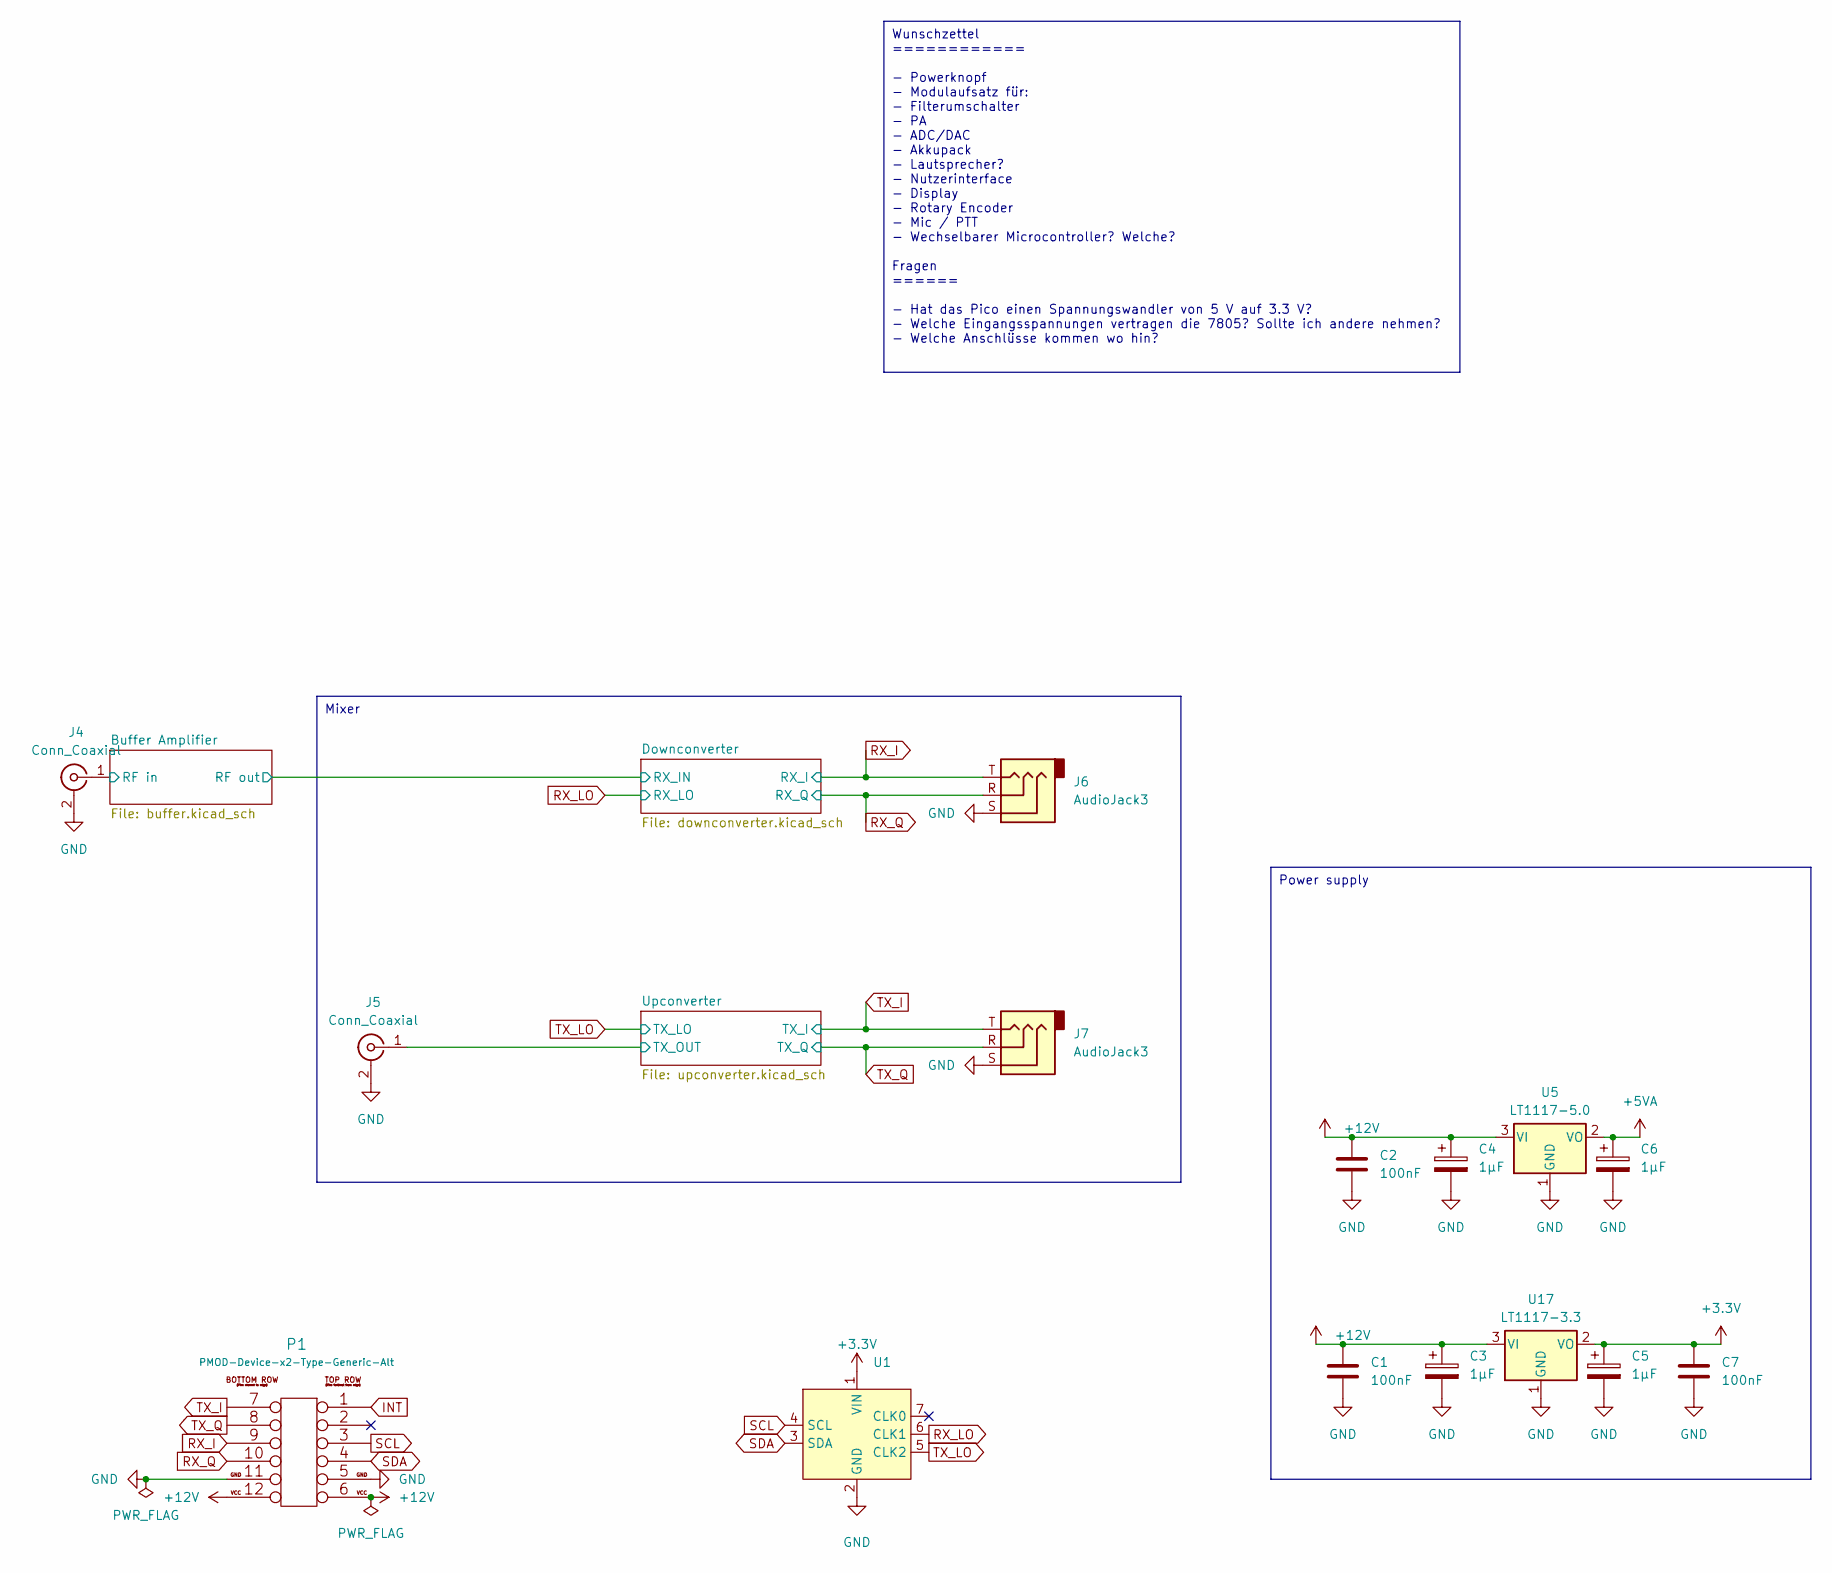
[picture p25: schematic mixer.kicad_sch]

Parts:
C1, C2, C7: 100nF; C_0603_1608Metric
C3, C4, C5, C6: 1µF; CP_EIA-3216-18_Kemet-A
J4, J5: Conn_Coaxial; SMA_Molex_73251-2200_Horizontal
J6, J7: AudioJack3; Jack_3.5mm_CUI_SJ1-3533NG_Horizontal
P1: PMOD-Device-x2-Type-Generic-Alt; pmod_pin_array_6x2
U1: Module_Si5351
U5: LT1117-5.0; SOT-223-3_TabPin2
U17: LT1117-3.3; SOT-223-3_TabPin2

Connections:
+3.3V: C5.1, C7.1, U1.1 (VIN), U17.2 (VO); also elsewhere on the board
+5VA: C6.1, U5.2 (VO); also elsewhere on the board
+12V: C1.1, C2.1, C3.1, C4.1, P1.6, P1.12, U5.3 (VI), U17.3 (VI)
/Buffer Amplifier/RF in: J4.1 (In); also elsewhere on the board
/Upconverter/TX_OUT: J5.1 (In); also elsewhere on the board
GND: C1.2, C2.2, C3.2, C4.2, C5.2, C6.2, C7.2, J4.2 (Ext), J5.2 (Ext), J6.S, J7.S, P1.5, P1.11, U1.2 (GND), U5.1 (GND), U17.1 (GND); also elsewhere on the board
INT: P1.1
RX_I: J6.T, P1.9; also elsewhere on the board
RX_LO: U1.6 (CLK1); also elsewhere on the board
RX_Q: J6.R, P1.10; also elsewhere on the board
SCL: P1.3, U1.4 (SCL)
SDA: P1.4, U1.3 (SDA)
TX_I: J7.T, P1.7; also elsewhere on the board
TX_LO: U1.5 (CLK2); also elsewhere on the board
TX_Q: J7.R, P1.8; also elsewhere on the board

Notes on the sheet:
Mixer
Power supply
Wunschzettel ============ - Powerknopf - Modulaufsatz für: - Filterumschalter - PA - ADC/DAC - Akkupack - Lautsprecher? - Nutzerinterface - Display - Rotary Encoder - Mic / PTT - Wechselbarer Microcontroller? Welche? Fragen ====== - Hat das Pico einen Spannungswandler von 5 V auf 3.3 V? - Welche Ei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

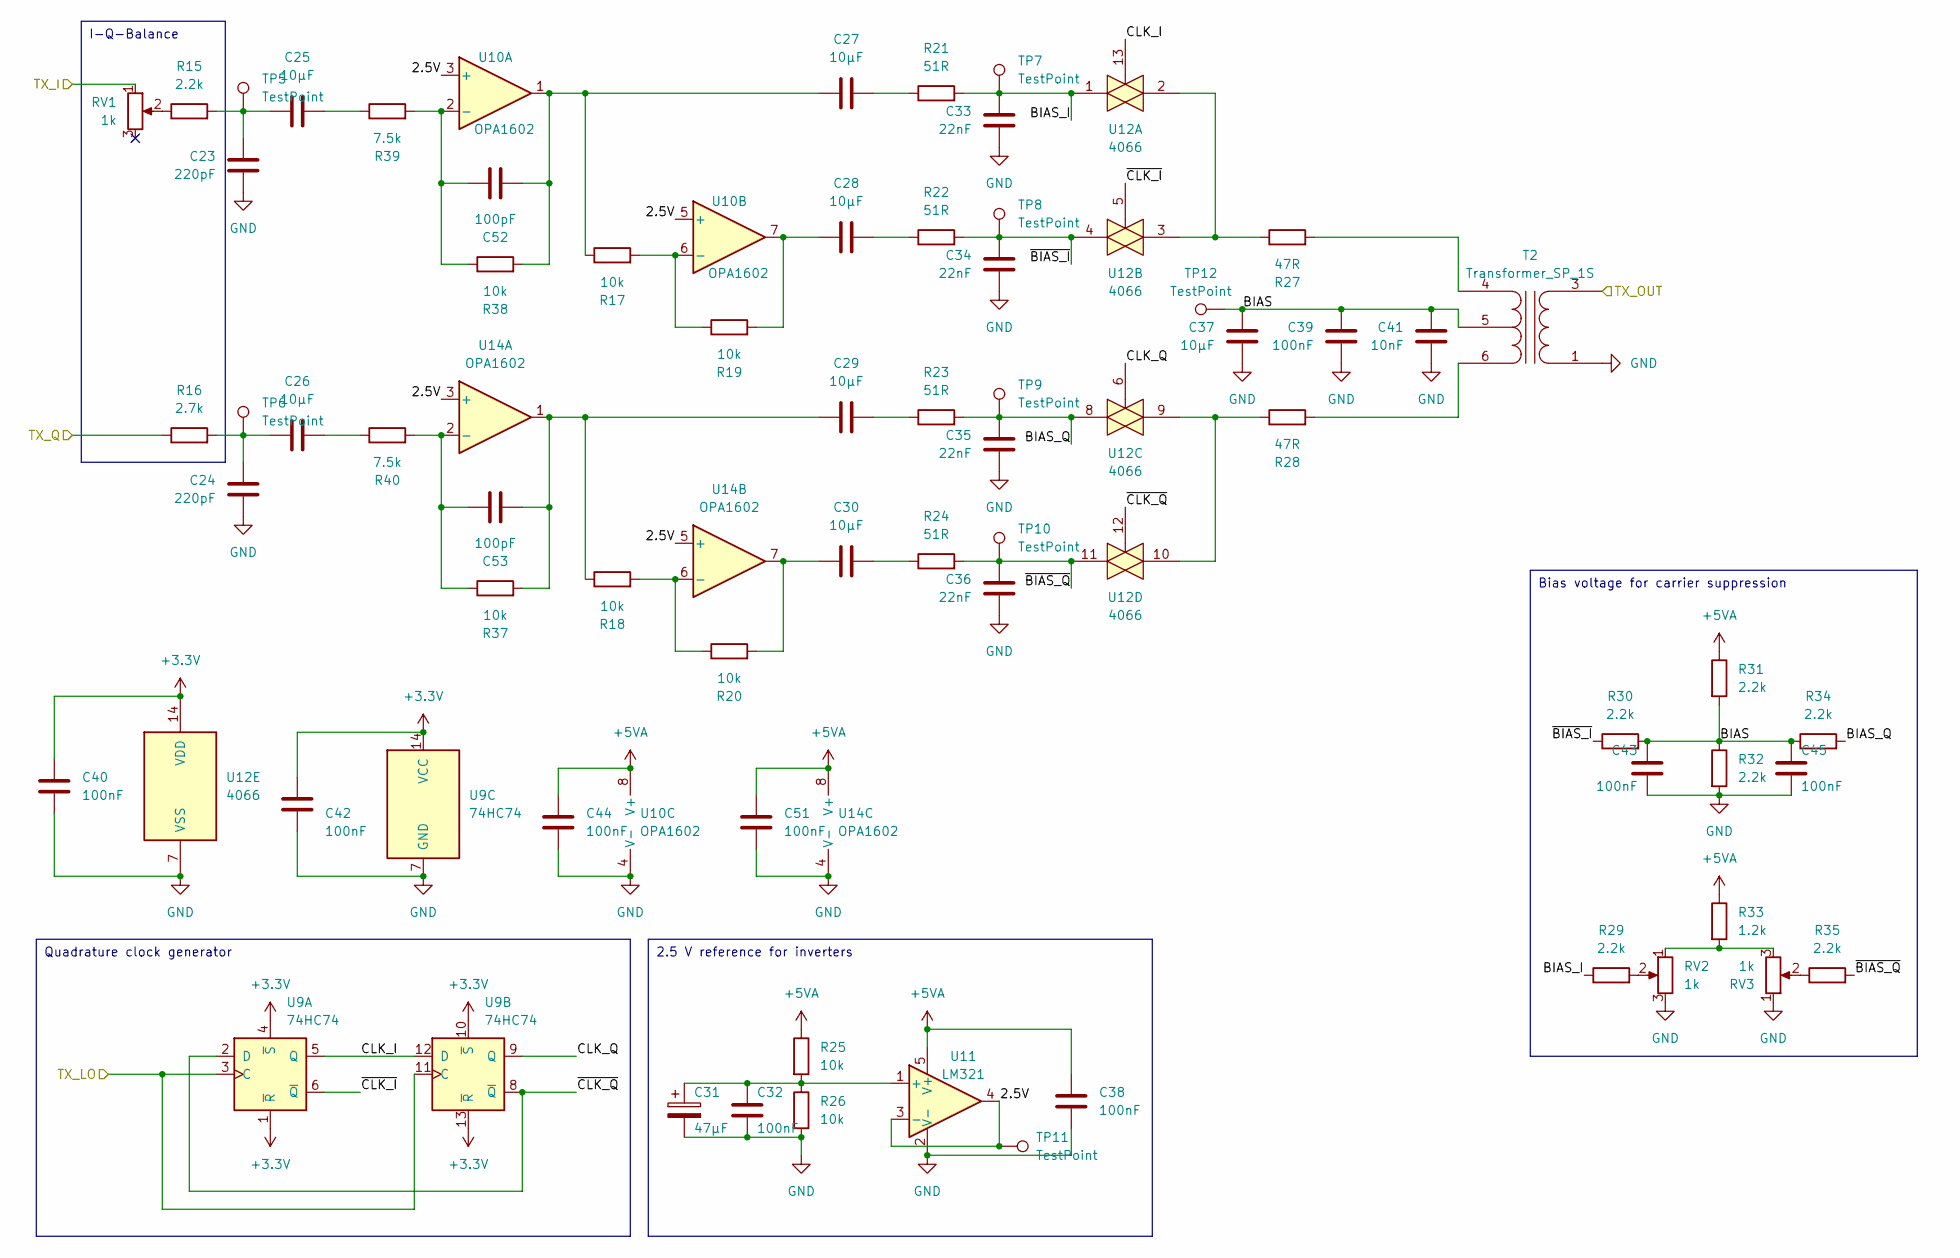
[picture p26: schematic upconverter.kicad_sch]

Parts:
C23, C24: 220pF; C_0603_1608Metric
C25, C26, C27, C28, C29, C30, C37: 10µF; C_1206_3216Metric
C31: 47µF; CP_Radial_D5.0mm_P2.00mm
C32, C38, C39, C40, C42, C43, C44, C45, C51: 100nF; C_0603_1608Metric
C33, C34, C35, C36: 22nF; C_0603_1608Metric
C41: 10nF; C_0603_1608Metric
C52, C53: 100pF; C_1206_3216Metric
R15, R29, R30, R31, R32, R34, R35: 2.2k; R_0603_1608Metric
R16: 2.7k; R_0603_1608Metric
R17, R18, R19, R20, R25, R26, R37, R38: 10k; R_0603_1608Metric
R21, R22, R23, R24: 51R; R_0603_1608Metric
R27, R28: 47R; R_0603_1608Metric
R33: 1.2k; R_0603_1608Metric
R39, R40: 7.5k; R_0603_1608Metric
RV1, RV2, RV3: 1k; Potentiometer_Piher_PT-10-H01_Horizontal
T2: Transformer_SP_1S; Transformer_MiniCircuits_ADT1-6T+
TP5, TP6, TP7, TP8, TP9, TP10, TP11, TP12: TestPoint; TestPoint_Loop_D1.80mm_Drill1.0mm_Beaded
U9: 74HC74; SOIC-14_3.9x8.7mm_P1.27mm
U10, U14: OPA1602; SOIC-8_3.9x4.9mm_P1.27mm
U11: LM321; SOT-23-5
U12: 4066; SOIC-14_3.9x8.7mm_P1.27mm

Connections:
+3.3V: C40.1, C42.1, U9.1 (~R), U9.4 (~S), U9.10 (~S), U9.13 (~R), U9.14 (VCC), U12.14 (VDD); also elsewhere on the board
+5VA: C38.1, C44.1, C51.1, R25.1, R31.1, R33.1, U10.8 (V+), U11.5 (V+), U14.8 (V+); also elsewhere on the board
/Upconverter/2.5V: TP11.1, U10.3 (+), U10.5 (+), U11.3 (-), U11.4, U14.3 (+), U14.5 (+)
/Upconverter/BIAS: C37.1, C39.1, C41.1, C43.1, C45.1, R30.2, R31.2, R32.1, R34.1, T2.5 (Secondary_CT), TP12.1
/Upconverter/BIAS_I: C33.1, R21.2, R29.1, TP7.1, U12.1
/Upconverter/BIAS_Q: C35.1, R23.2, R34.2, TP9.1, U12.8
/Upconverter/CLK_I: U9.5 (Q), U9.12 (D), U12.13
/Upconverter/CLK_Q: U9.9 (Q), U12.6
/Upconverter/TX_OUT: T2.3 (Primary_dot); also elsewhere on the board
/Upconverter/~BIAS_I: C34.1, R22.2, R30.1, TP8.1, U12.4
/Upconverter/~BIAS_Q: C36.1, R24.2, R35.2, TP10.1, U12.11
/Upconverter/~CLK_I: U9.6 (~Q), U12.5
/Upconverter/~CLK_Q: U9.2 (D), U9.8 (~Q), U12.12
GND: C23.2, C24.2, C31.2, C32.2, C33.2, C34.2, C35.2, C36.2, C37.2, C38.2, C39.2, C40.2, C41.2, C42.2, C43.2, C44.2, C45.2, C51.2, R26.2, R32.2, RV2.3, RV3.1, T2.1 (Primary), U9.7 (GND), U10.4 (V-), U11.2 (V-), U12.7 (VSS), U14.4 (V-); also elsewhere on the board
unnamed: C23.1, C25.1, R15.2, TP5.1
unnamed: C24.1, C26.1, R16.2, TP6.1
unnamed: C25.2, R39.1
unnamed: C26.2, R40.1
unnamed: C27.1, C52.2, R17.1, R38.2, U10.1
unnamed: C27.2, R21.1
unnamed: C28.1, R19.2, U10.7
unnamed: C28.2, R22.1
unnamed: C29.1, C53.2, R18.1, R37.2, U14.1
unnamed: C29.2, R23.1
unnamed: C30.1, R20.2, U14.7
unnamed: C30.2, R24.1
unnamed: R15.1, RV1.2
unnamed: R27.1, U12.2, U12.3
unnamed: R27.2, T2.4 (Secondary_dot)
unnamed: R28.1, U12.9, U12.10
unnamed: R28.2, T2.6 (Secondary_dot)
unnamed: R29.2, RV2.2
unnamed: R33.2, RV2.1, RV3.3
unnamed: R35.1, RV3.2
unnamed: C52.1, R38.1, R39.2, U10.2 (-)
unnamed: R17.2, R19.1, U10.6 (-)
unnamed: C31.1, C32.1, R25.2, R26.1, U11.1 (+)
unnamed: C53.1, R37.1, R40.2, U14.2 (-)
unnamed: R18.2, R20.1, U14.6 (-)
TX_I: RV1.1; also elsewhere on the board
TX_LO: U9.3 (C), U9.11 (C); also elsewhere on the board
TX_Q: R16.1; also elsewhere on the board

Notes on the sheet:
I-Q-Balance
Quadrature clock generator
2.5 V reference for inverters
Bias voltage for carrier suppression

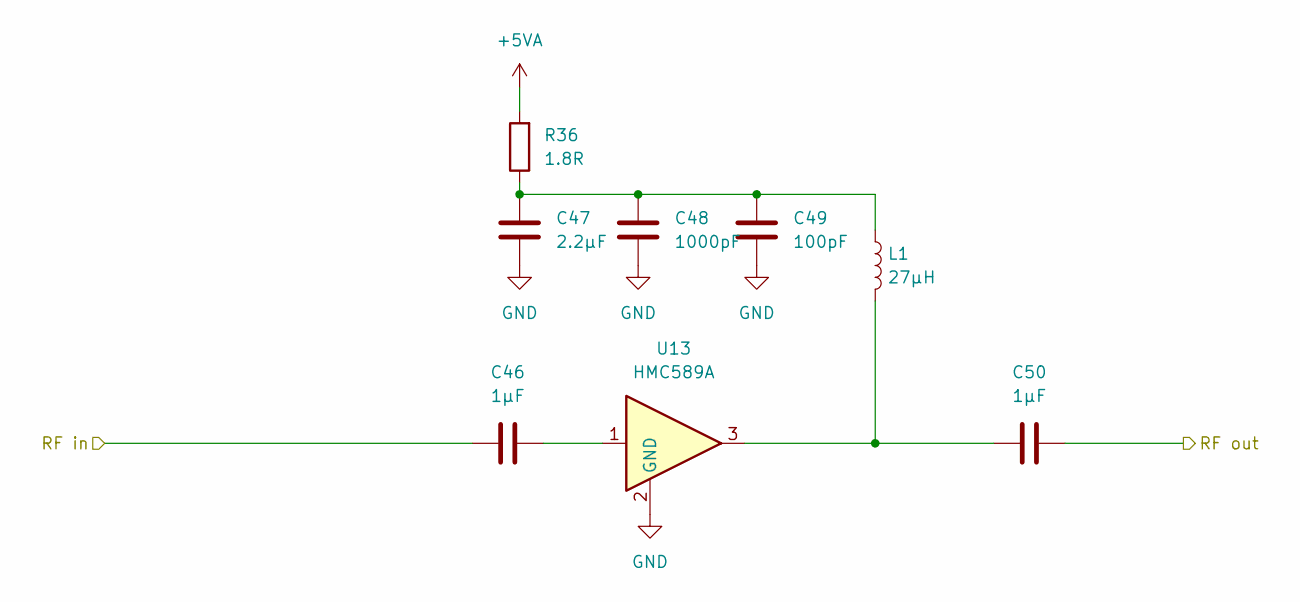
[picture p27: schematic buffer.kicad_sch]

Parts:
C46, C50: 1µF; C_0603_1608Metric
C47: 2.2µF; C_0603_1608Metric
C48: 1000pF; C_0603_1608Metric
C49: 100pF; C_0603_1608Metric
L1: 27µH; L_Bourns_SRR1208_12.7x12.7mm
R36: 1.8R; R_0603_1608Metric
U13: HMC589A; SOT-89-3

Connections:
+5VA: R36.2; also elsewhere on the board
/Buffer Amplifier/RF in: C46.1; also elsewhere on the board
/Buffer Amplifier/RF out: C50.2; also elsewhere on the board
GND: C47.2, C48.2, C49.2, U13.2 (GND); also elsewhere on the board
unnamed: C46.2, U13.1
unnamed: C47.1, C48.1, C49.1, L1.1, R36.1
unnamed: C50.1, L1.2, U13.3

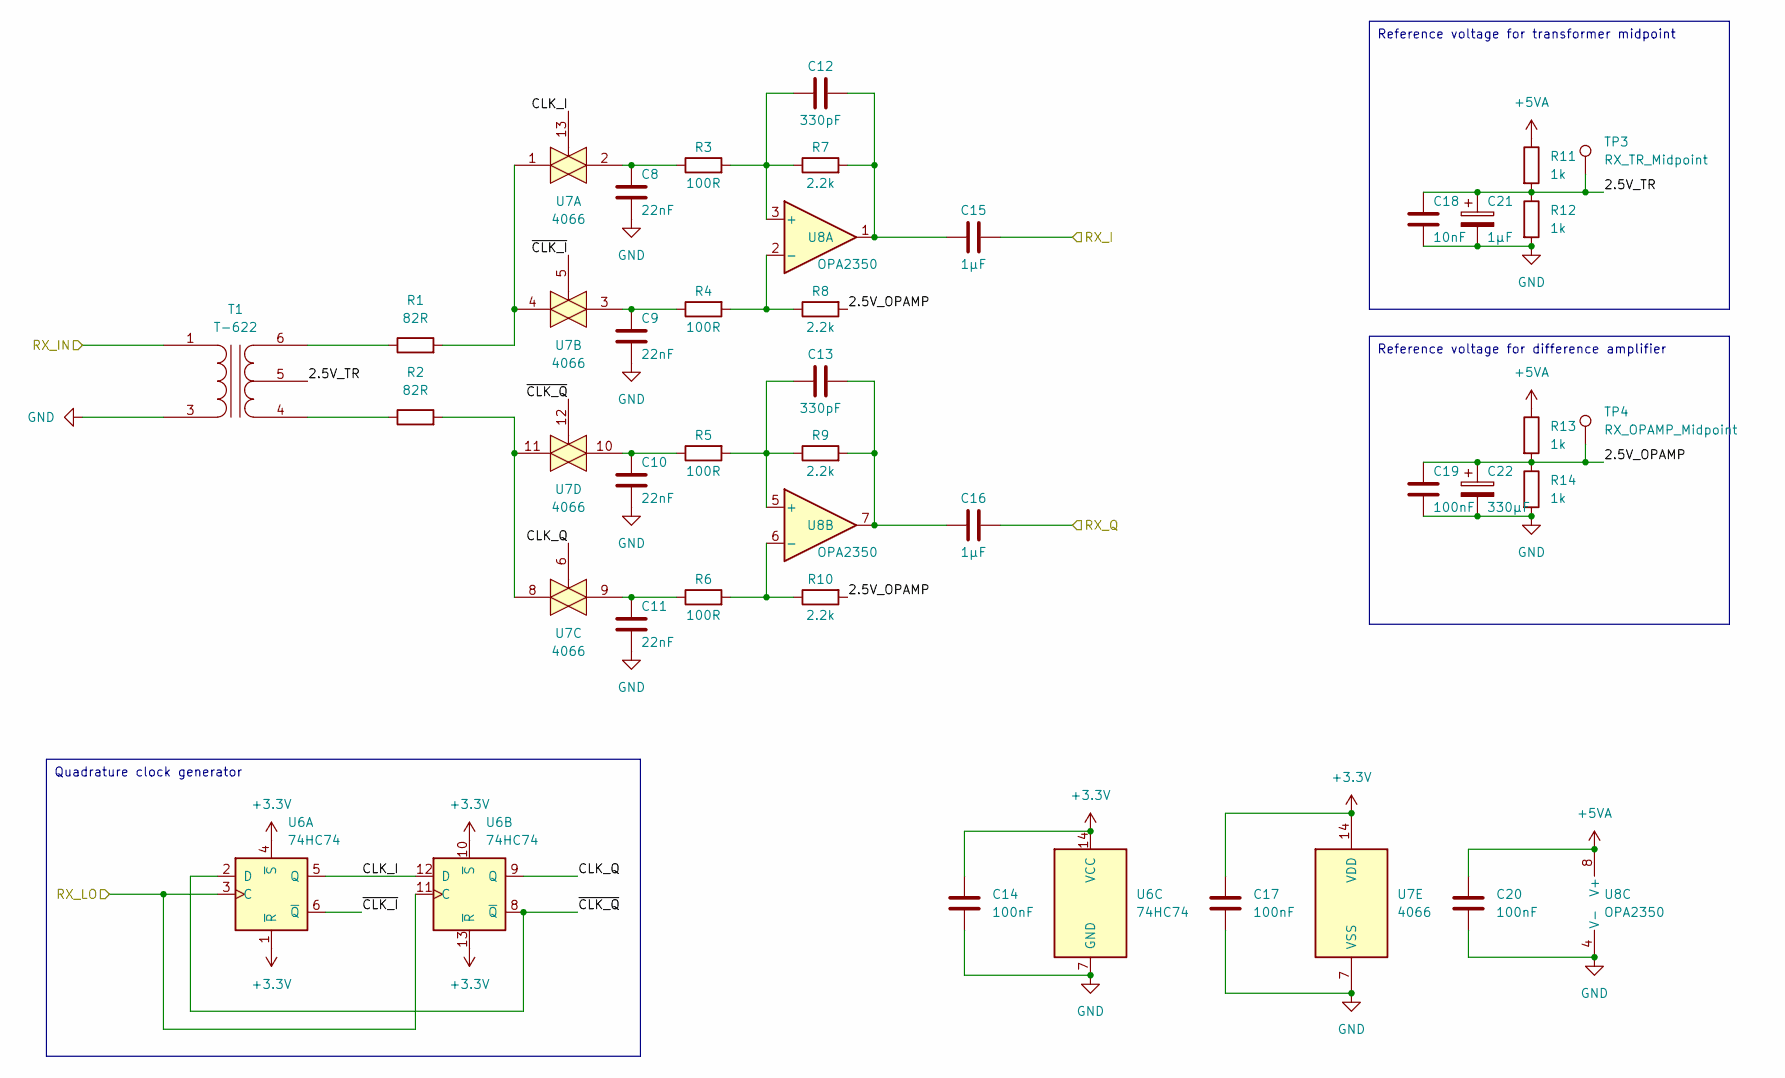
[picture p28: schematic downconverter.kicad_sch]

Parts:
C8, C9, C10, C11: 22nF; C_0603_1608Metric
C12, C13: 330pF; C_0603_1608Metric
C14, C17, C19, C20: 100nF; C_0603_1608Metric
C15, C16: 1µF; C_0603_1608Metric
C18: 10nF; C_0603_1608Metric
C21: 1µF; CP_EIA-3216-18_Kemet-A
C22: 330µF; C_Radial_D6.3mm_H11.0mm_P2.50mm
R1, R2: 82R; R_0603_1608Metric
R3, R4, R5, R6: 100R; R_0603_1608Metric
R7, R8, R9, R10: 2.2k; R_0603_1608Metric
R11, R12, R13, R14: 1k; R_0603_1608Metric
T1: T-622; Transformer_MiniCircuits_ADT1-6T+
TP3: RX_TR_Midpoint; TestPoint_Loop_D1.80mm_Drill1.0mm_Beaded
TP4: RX_OPAMP_Midpoint; TestPoint_Loop_D1.80mm_Drill1.0mm_Beaded
U6: 74HC74; SOIC-14_3.9x8.7mm_P1.27mm
U7: 4066; SOIC-14_3.9x8.7mm_P1.27mm
U8: OPA2350; SOIC-8_3.9x4.9mm_P1.27mm

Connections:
+3.3V: C14.1, C17.1, U6.1 (~R), U6.4 (~S), U6.10 (~S), U6.13 (~R), U6.14 (VCC), U7.14 (VDD); also elsewhere on the board
+5VA: C20.1, R11.1, R13.1, U8.8 (V+); also elsewhere on the board
/Buffer Amplifier/RF out: T1.1 (Primary); also elsewhere on the board
/Downconverter/2.5V_OPAMP: C19.1, C22.1, R8.2, R10.2, R13.2, R14.1, TP4.1
/Downconverter/2.5V_TR: C18.1, C21.1, R11.2, R12.1, T1.5 (Secondary_CT), TP3.1
/Downconverter/CLK_I: U6.5 (Q), U6.12 (D), U7.13
/Downconverter/CLK_Q: U6.9 (Q), U7.6
/Downconverter/~CLK_I: U6.6 (~Q), U7.5
/Downconverter/~CLK_Q: U6.2 (D), U6.8 (~Q), U7.12
GND: C8.1, C9.1, C10.1, C11.1, C14.2, C17.2, C18.2, C19.2, C20.2, C21.2, C22.2, R12.2, R14.2, T1.3 (Primary_dot), U6.7 (GND), U7.7 (VSS), U8.4 (V-); also elsewhere on the board
unnamed: C8.2, R3.1, U7.2
unnamed: C9.2, R4.1, U7.3
unnamed: C10.2, R5.1, U7.10
unnamed: C11.2, R6.1, U7.9
unnamed: C12.1, C15.2, R7.2, U8.1
unnamed: C13.1, C16.2, R9.2, U8.7
unnamed: R1.1, T1.6 (Secondary_dot)
unnamed: R1.2, U7.1, U7.4
unnamed: R2.1, T1.4 (Secondary_dot)
unnamed: R2.2, U7.8, U7.11
unnamed: C12.2, R3.2, R7.1, U8.3 (+)
unnamed: R4.2, R8.1, U8.2 (-)
unnamed: C13.2, R5.2, R9.1, U8.5 (+)
unnamed: R6.2, R10.1, U8.6 (-)
RX_I: C15.1; also elsewhere on the board
RX_LO: U6.3 (C), U6.11 (C); also elsewhere on the board
RX_Q: C16.1; also elsewhere on the board

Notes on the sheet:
Quadrature clock generator
Reference voltage for difference amplifier
Reference voltage for transformer midpoint

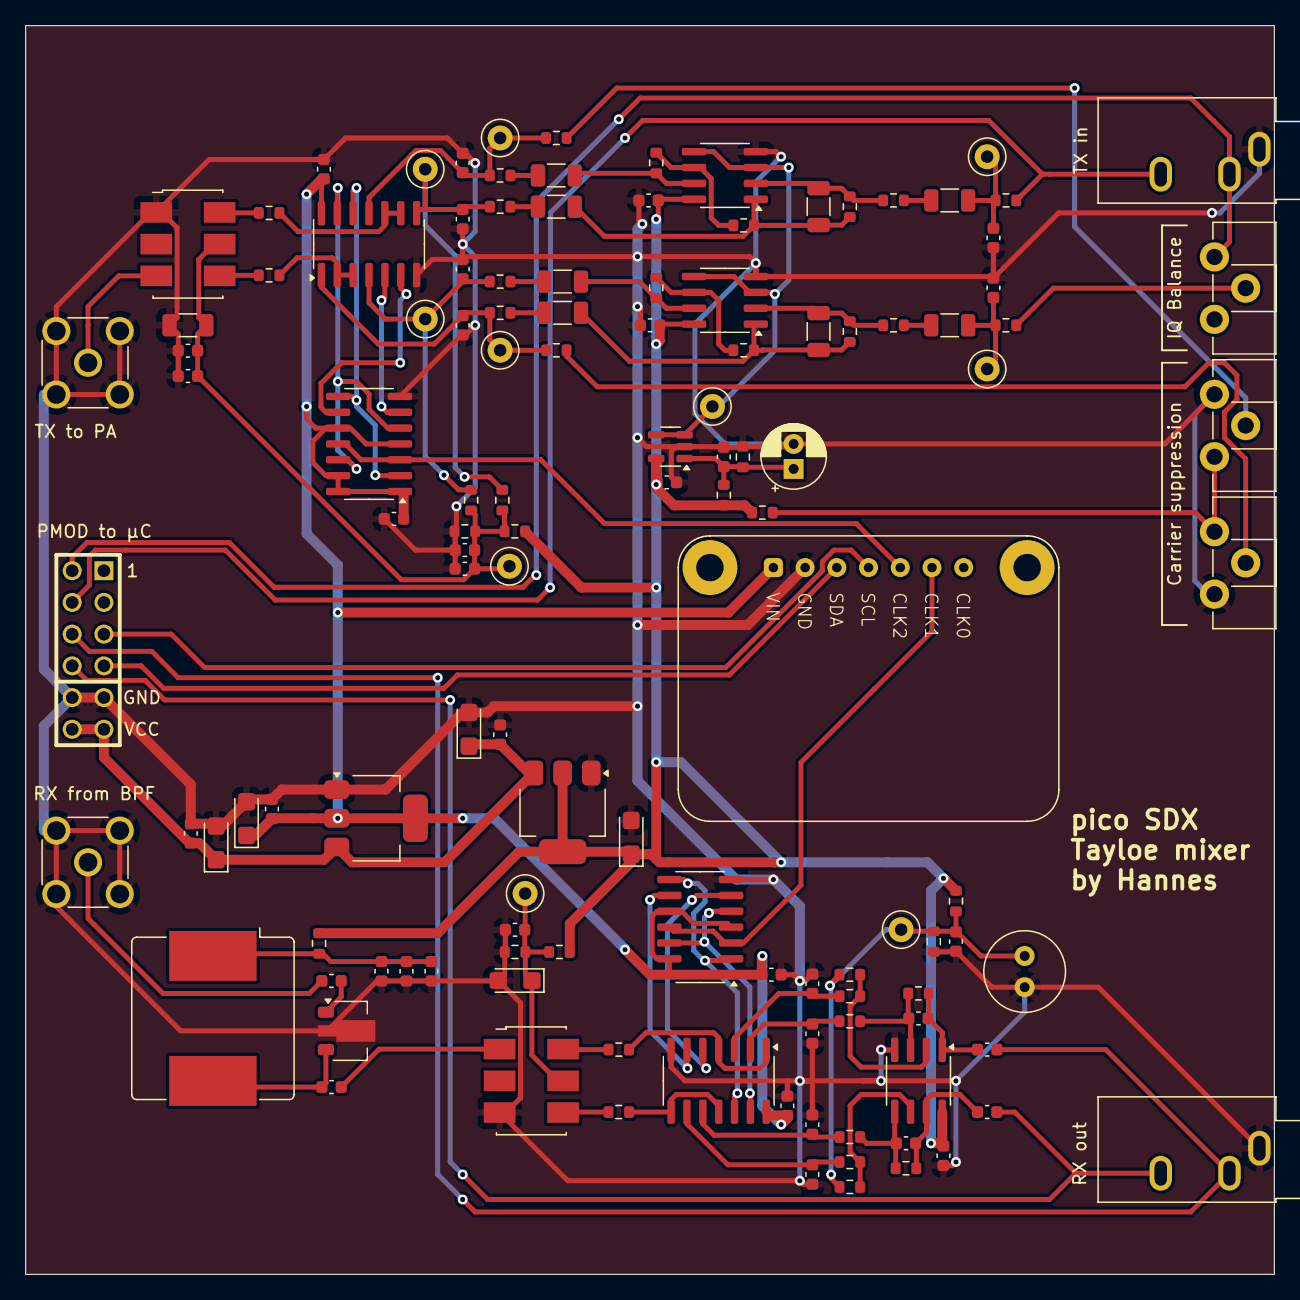
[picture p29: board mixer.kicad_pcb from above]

Board: 2 copper layers, 100.0 x 100.0 mm, 126 parts (0 on the bottom side), 73 nets.

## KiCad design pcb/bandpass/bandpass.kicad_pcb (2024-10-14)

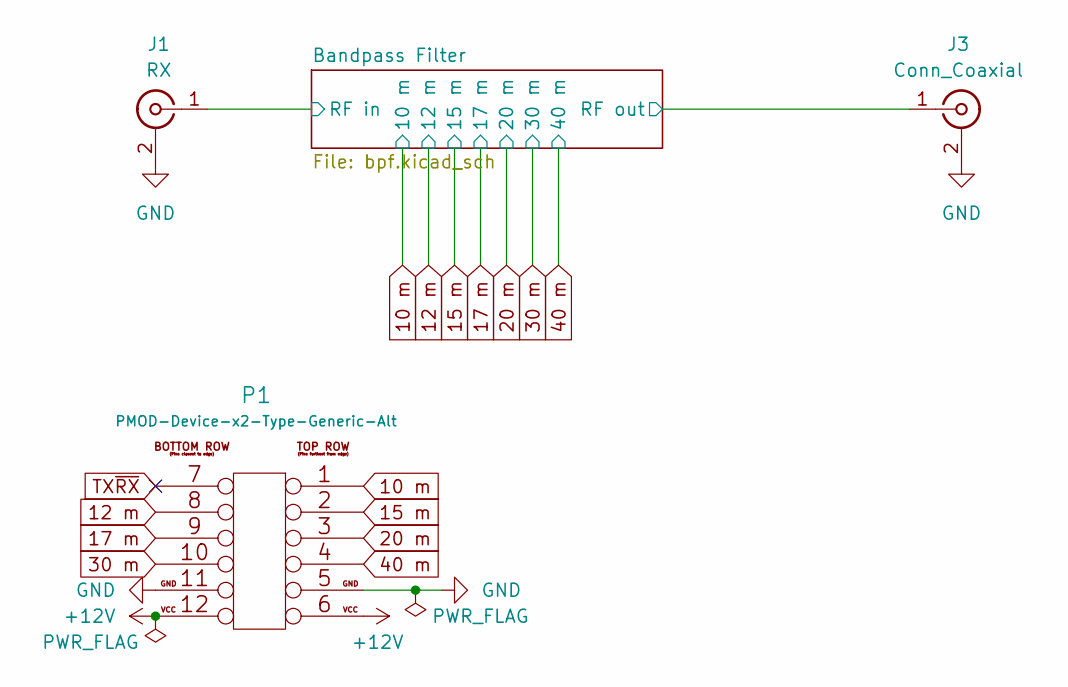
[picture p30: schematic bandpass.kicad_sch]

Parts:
J1: RX; SMA_Molex_73251-2200_Horizontal
J3: Conn_Coaxial; SMA_Molex_73251-2200_Horizontal
P1: PMOD-Device-x2-Type-Generic-Alt; pmod_pin_array_6x2

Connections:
10 m: P1.1; also elsewhere on the board
12 m: P1.8; also elsewhere on the board
15 m: P1.2; also elsewhere on the board
17 m: P1.9; also elsewhere on the board
20 m: P1.3; also elsewhere on the board
30 m: P1.10; also elsewhere on the board
40 m: P1.4; also elsewhere on the board
+12V: P1.6, P1.12; also elsewhere on the board
/Bandpass Filter/RF in: J1.1 (In); also elsewhere on the board
/Bandpass Filter/RF out: J3.1 (In); also elsewhere on the board
GND: J1.2 (Ext), J3.2 (Ext), P1.5, P1.11; also elsewhere on the board
TX~RX: P1.7

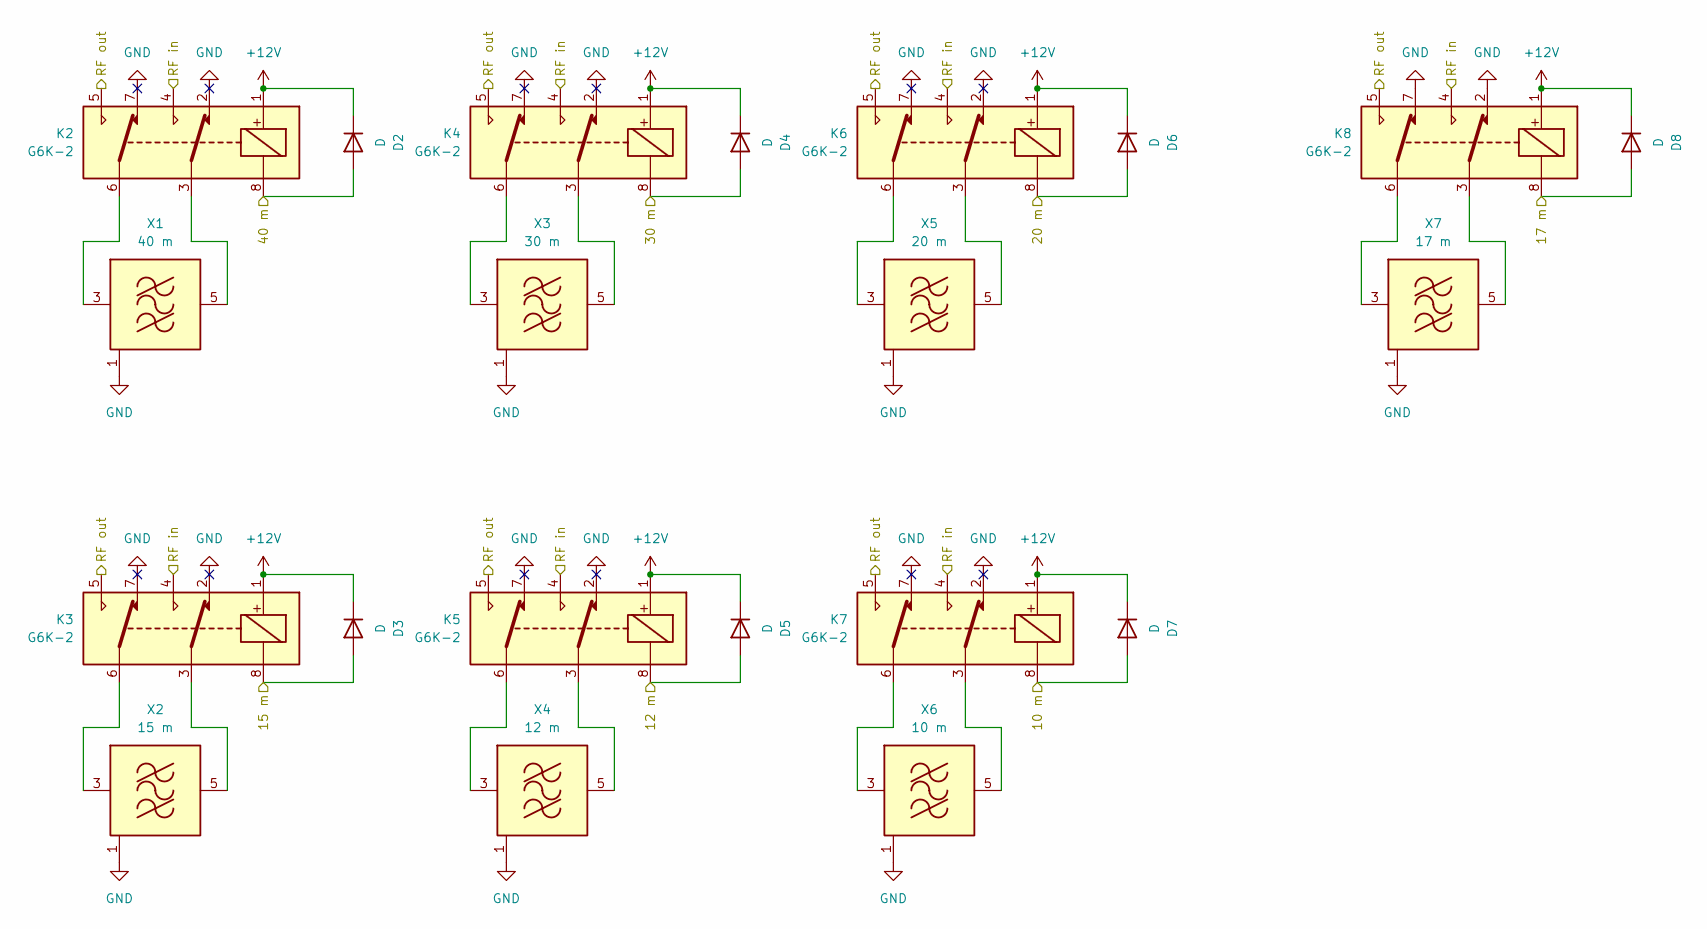
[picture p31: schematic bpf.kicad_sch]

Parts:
D2, D3, D4, D5, D6, D7, D8: D; D_SOD-128
K2, K3, K4, K5, K6, K7, K8: G6K-2; Relay_DPDT_Omron_G6K-2P
X1: 40 m; Filter Module
X2: 15 m; Filter Module
X3: 30 m; Filter Module
X4: 12 m; Filter Module
X5: 20 m; Filter Module
X6: 10 m; Filter Module
X7: 17 m; Filter Module

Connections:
10 m: D7.2 (A), K7.8; also elsewhere on the board
12 m: D5.2 (A), K5.8; also elsewhere on the board
15 m: D3.2 (A), K3.8; also elsewhere on the board
17 m: D8.2 (A), K8.8; also elsewhere on the board
20 m: D6.2 (A), K6.8; also elsewhere on the board
30 m: D4.2 (A), K4.8; also elsewhere on the board
40 m: D2.2 (A), K2.8; also elsewhere on the board
+12V: D2.1 (K), D3.1 (K), D4.1 (K), D5.1 (K), D6.1 (K), D7.1 (K), D8.1 (K), K2.1, K3.1, K4.1, K5.1, K6.1, K7.1, K8.1; also elsewhere on the board
/Bandpass Filter/RF in: K2.4, K3.4, K4.4, K5.4, K6.4, K7.4, K8.4; also elsewhere on the board
/Bandpass Filter/RF out: K2.5, K3.5, K4.5, K5.5, K6.5, K7.5, K8.5; also elsewhere on the board
GND: K2.2, K2.7, K3.2, K3.7, K4.2, K4.7, K5.2, K5.7, K6.2, K6.7, K7.2, K7.7, K8.2, K8.7, X1.1 (GND), X1.2 (GND), X1.7 (GND), X1.8 (GND), X2.1 (GND), X2.2 (GND), X2.7 (GND), X2.8 (GND), X3.1 (GND), X3.2 (GND), X3.7 (GND), X3.8 (GND), X4.1 (GND), X4.2 (GND), X4.7 (GND), X4.8 (GND), X5.1 (GND), X5.2 (GND), X5.7 (GND), X5.8 (GND), X6.1 (GND), X6.2 (GND), X6.7 (GND), X6.8 (GND), X7.1 (GND), X7.2 (GND), X7.7 (GND), X7.8 (GND); also elsewhere on the board
unnamed: K2.3, X1.5 (OUT), X1.6 (OUT)
unnamed: K2.6, X1.3 (IN), X1.4 (IN)
unnamed: K3.3, X2.5 (OUT), X2.6 (OUT)
unnamed: K3.6, X2.3 (IN), X2.4 (IN)
unnamed: K4.3, X3.5 (OUT), X3.6 (OUT)
unnamed: K4.6, X3.3 (IN), X3.4 (IN)
unnamed: K5.3, X4.5 (OUT), X4.6 (OUT)
unnamed: K5.6, X4.3 (IN), X4.4 (IN)
unnamed: K6.3, X5.5 (OUT), X5.6 (OUT)
unnamed: K6.6, X5.3 (IN), X5.4 (IN)
unnamed: K7.3, X6.5 (OUT), X6.6 (OUT)
unnamed: K7.6, X6.3 (IN), X6.4 (IN)
unnamed: K8.3, X7.5 (OUT), X7.6 (OUT)
unnamed: K8.6, X7.3 (IN), X7.4 (IN)

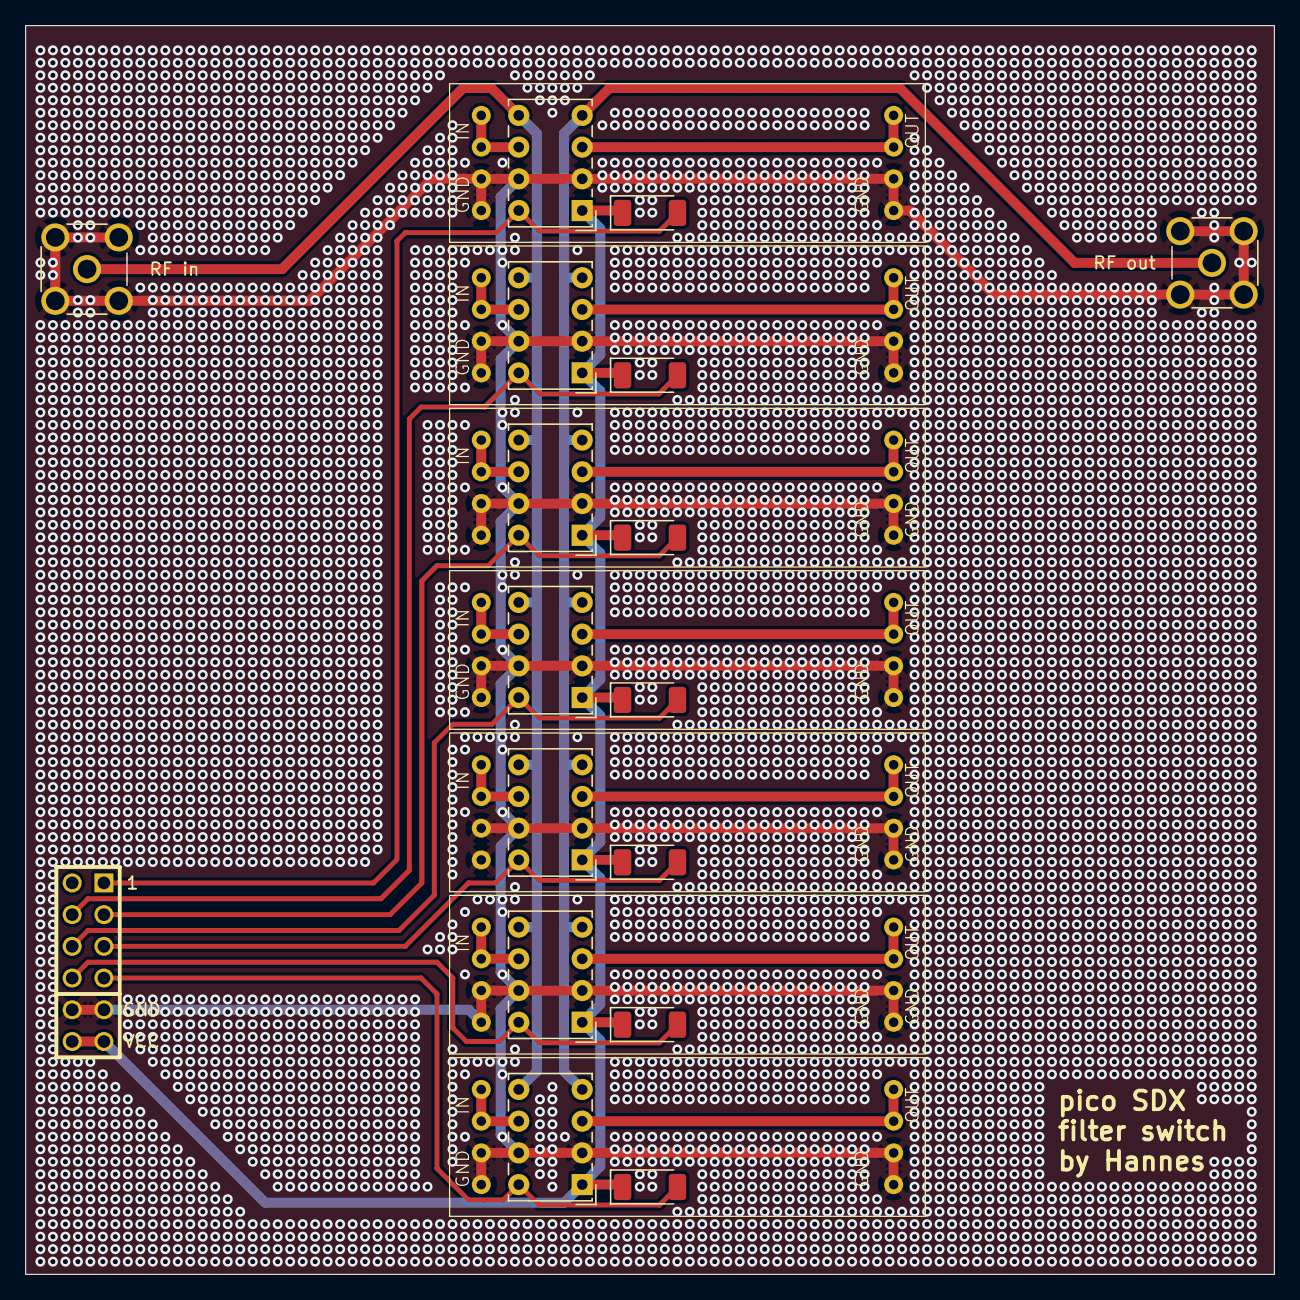
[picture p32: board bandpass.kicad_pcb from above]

Board: 2 copper layers, 100.0 x 100.0 mm, 24 parts (0 on the bottom side), 25 nets.

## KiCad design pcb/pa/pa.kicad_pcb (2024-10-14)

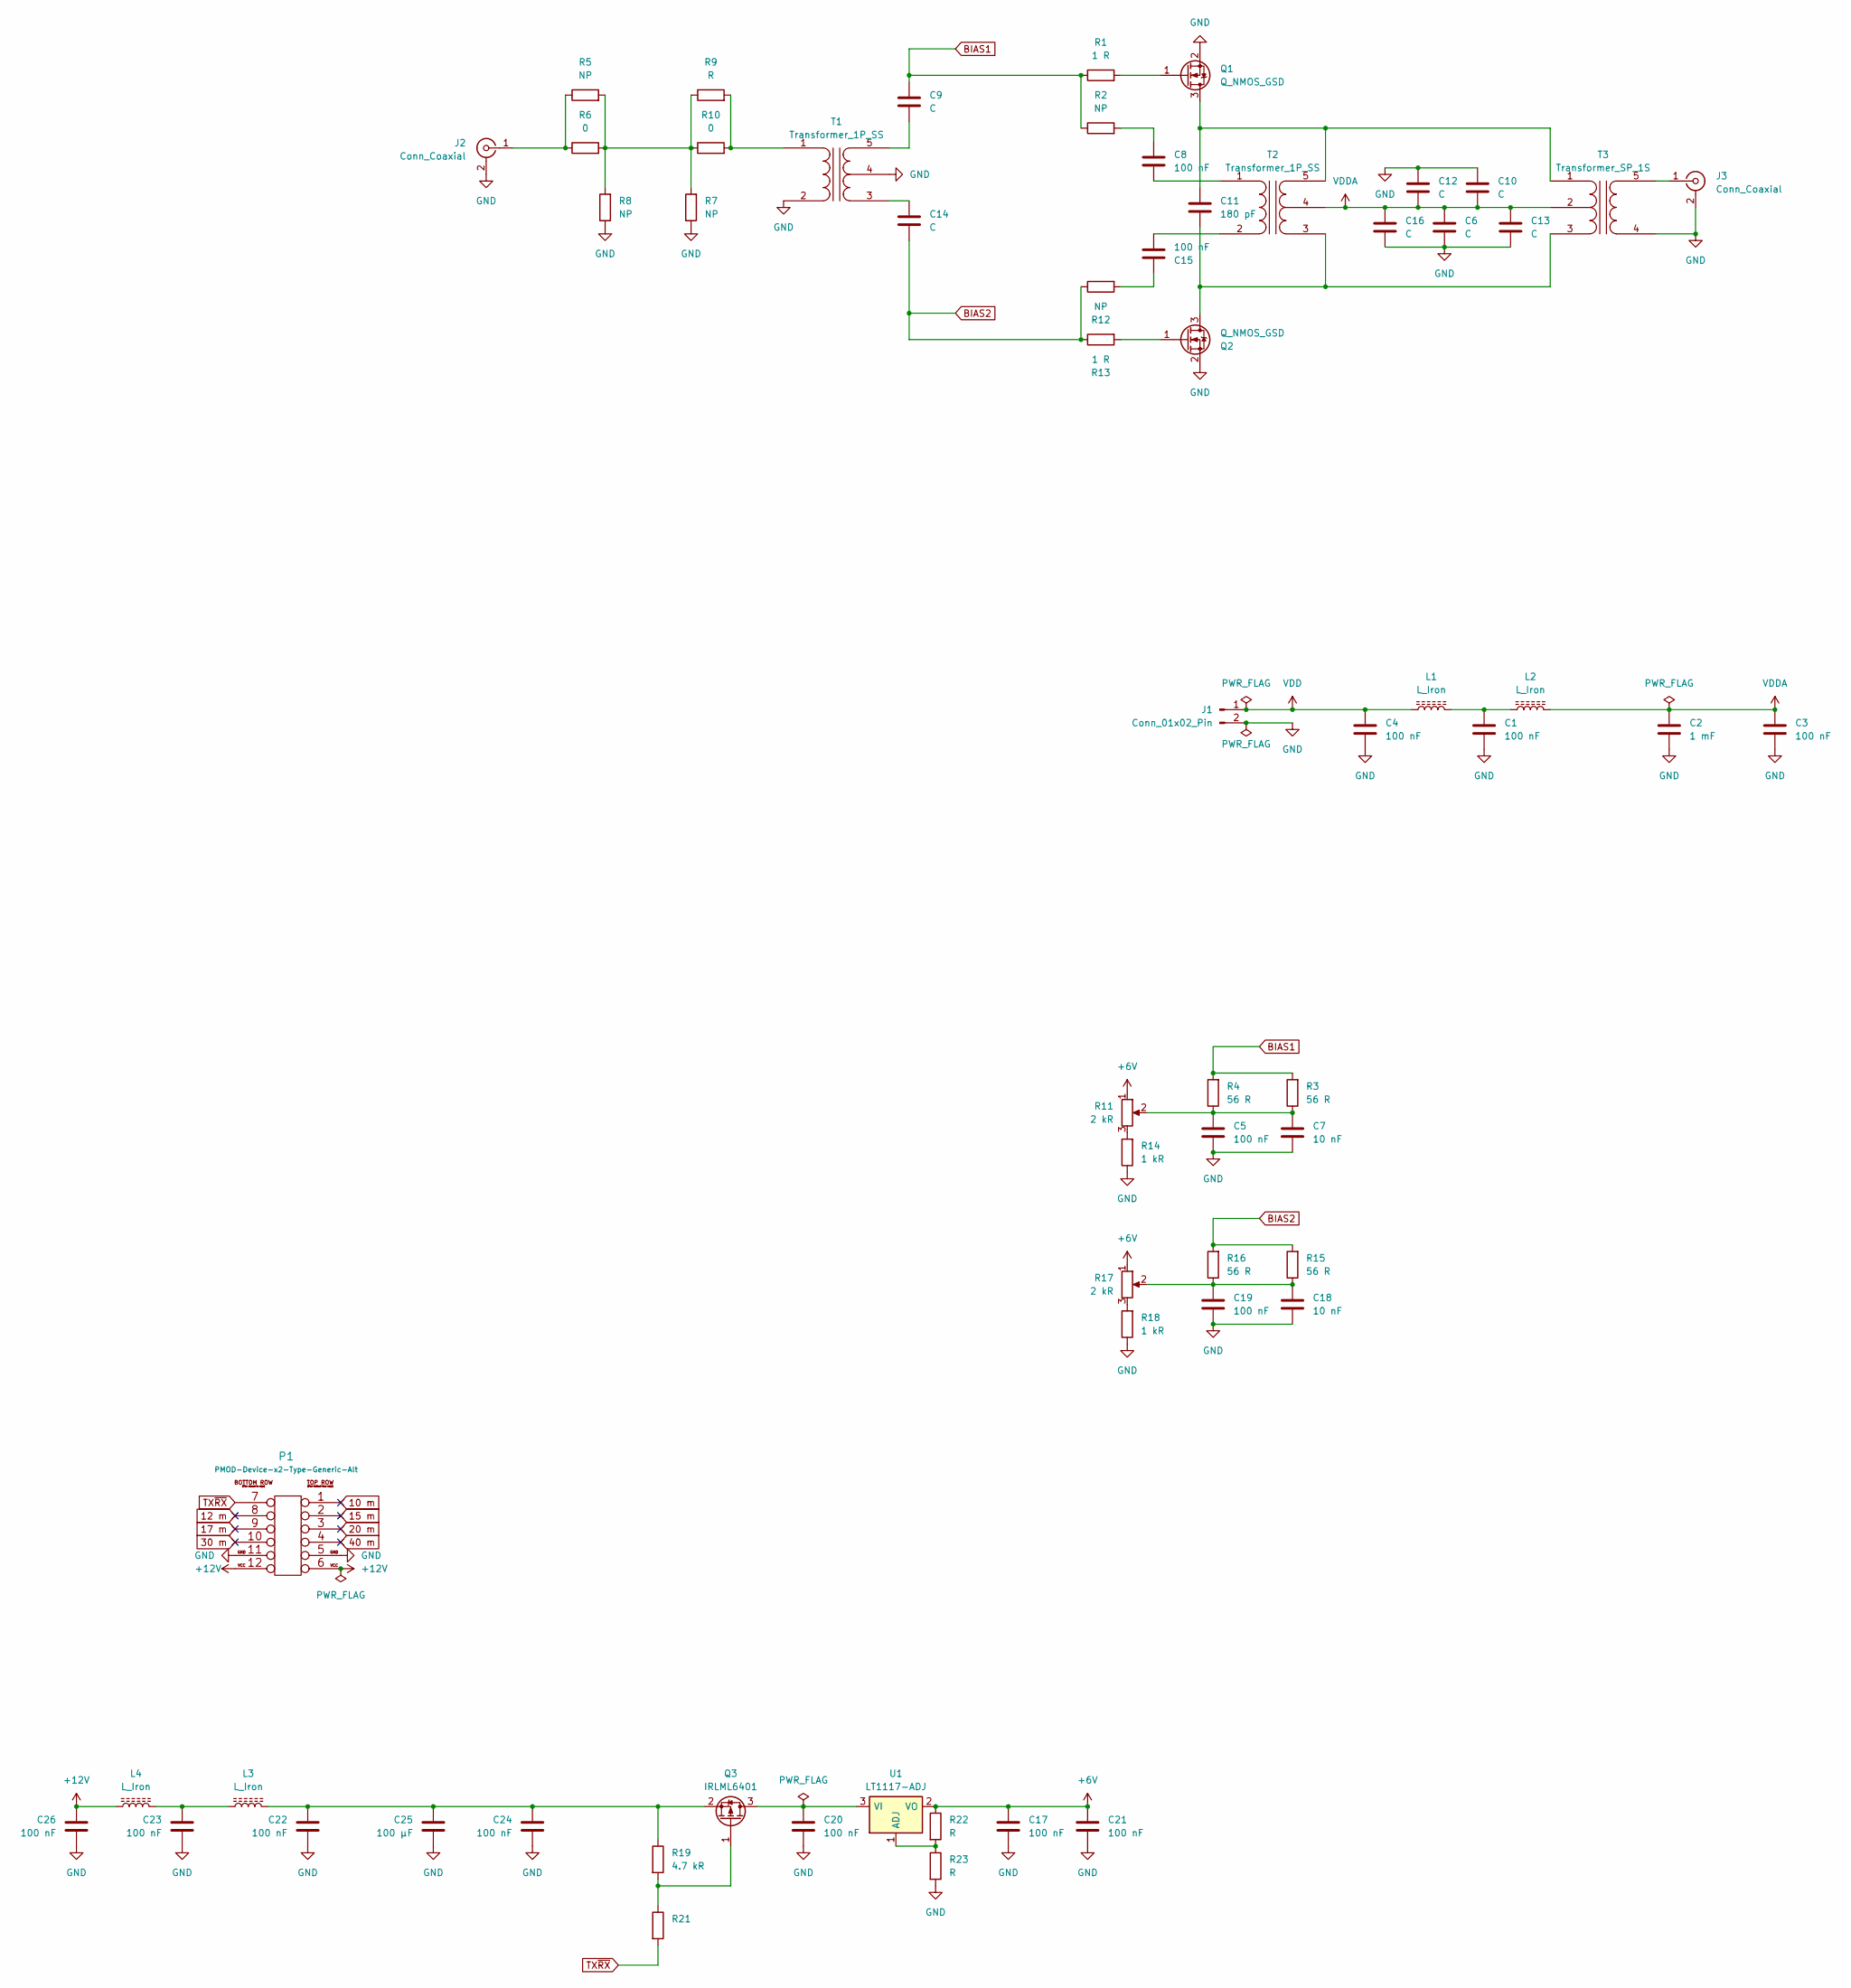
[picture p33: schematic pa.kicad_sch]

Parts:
C1, C3, C4, C5, C8, C15, C17, C19, C20, C21, C22, C23, C24, C26: 100 nF; C_1206_3216Metric
C2: 1 mF; CAP_H32F_CND
C6, C9, C10, C12, C13, C14, C16: C; C_1206_3216Metric
C7, C18: 10 nF; C_1206_3216Metric
C11: 180 pF; C_1210_3225Metric
C25: 100 µF; CP_Elec_8x10
J1: Conn_01x02_Pin; JST_VH_S2P-VH_1x02_P3.96mm_Horizontal
J2, J3: Conn_Coaxial; SMA_Molex_73251-2200_Horizontal
L1, L2: L_Iron; L_Axial_L11.0mm_D4.5mm_P7.62mm_Vertical_Fastron_MECC
L3, L4: L_Iron; L_Axial_L7.0mm_D3.3mm_P5.08mm_Vertical_Fastron_MICC
P1: PMOD-Device-x2-Type-Generic-Alt; pmod_pin_array_6x2
Q1, Q2: Q_NMOS_GSD; TO-220F-3_Horizontal_TabDown
Q3: IRLML6401; SOT-23
R1, R13: 1 R; R_1206_3216Metric
R2, R5, R7, R8, R12: NP; R_1206_3216Metric
R3, R4, R15, R16: 56 R; R_1206_3216Metric
R6, R10: 0; R_1206_3216Metric
R9: R; R_1206_3216Metric
R11, R17: 2 kR; Potentiometer_Bourns_3296W_Vertical
R14, R18: 1 kR; R_1206_3216Metric
R19: 4.7 kR; R_1206_3216Metric
R21: R_1206_3216Metric
R22, R23: R; R_0603_1608Metric
T1: Transformer_1P_SS; Transformer 1
T2: Transformer_1P_SS; Transformer 2
T3: Transformer_SP_1S; Transformer 3
U1: LT1117-ADJ; SOT-223-3_TabPin2

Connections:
10 m: P1.1
12 m: P1.8
15 m: P1.2
17 m: P1.9
20 m: P1.3
30 m: P1.10
40 m: P1.4
+6V: C17.1, C21.1, R11.1, R17.1, R22.1, U1.2 (VO)
+12V: C26.1, L4.1, P1.6, P1.12
BIAS1: C9.1, R1.1, R2.1, R3.2, R4.2
BIAS2: C14.2, R12.1, R13.1, R15.2, R16.2
GND: C1.2, C2.2, C3.2, C4.2, C5.2, C6.2, C7.2, C10.1, C12.1, C13.2, C16.2, C17.2, C18.2, C19.2, C20.2, C21.2, C22.2, C23.2, C24.2, C25.2, C26.2, J1.2, J2.2 (Ext), J3.2 (Ext), P1.5, P1.11, Q1.2 (S), Q2.2 (S), R7.1, R8.1, R14.1, R18.1, R23.2, T1.2 (AB), T1.4 (SC), T3.4 (S1)
unnamed: C1.1, L1.1, L2.1
unnamed: C5.1, C7.1, R3.1, R4.1, R11.2
unnamed: C8.1, R2.2
unnamed: C15.1, R12.2
unnamed: C18.1, C19.1, R15.1, R16.1, R17.2
unnamed: C23.1, L3.1, L4.2
unnamed: J2.1 (In), R5.1, R6.1
unnamed: J3.1 (In), T3.5 (S2)
unnamed: C11.1, Q1.3 (D), T2.5 (SB), T3.1 (PR1)
unnamed: Q1.1 (G), R1.2
unnamed: C11.2, Q2.3 (D), T2.3 (SA), T3.3 (PR2)
unnamed: Q2.1 (G), R13.2
unnamed: C20.1, Q3.3 (D), U1.3 (VI)
unnamed: Q3.1 (G), R19.2, R21.1
unnamed: C22.1, C24.1, C25.1, L3.2, Q3.2 (S), R19.1
unnamed: R5.2, R6.2, R7.2, R8.2, R9.1, R10.1
unnamed: R11.3, R14.2
unnamed: R17.3, R18.2
unnamed: R9.2, R10.2, T1.1 (AA)
unnamed: C14.1, T1.3 (SA)
unnamed: C9.2, T1.5 (SB)
unnamed: C8.2, T2.1 (AA)
unnamed: C15.2, T2.2 (AB)
unnamed: R22.2, R23.1, U1.1 (ADJ)
TX~RX: P1.7, R21.2
VDD: C4.1, J1.1, L1.2
VDDA: C2.1, C3.1, C6.1, C10.2, C12.2, C13.1, C16.1, L2.2, T2.4 (SC), T3.2 (PM)

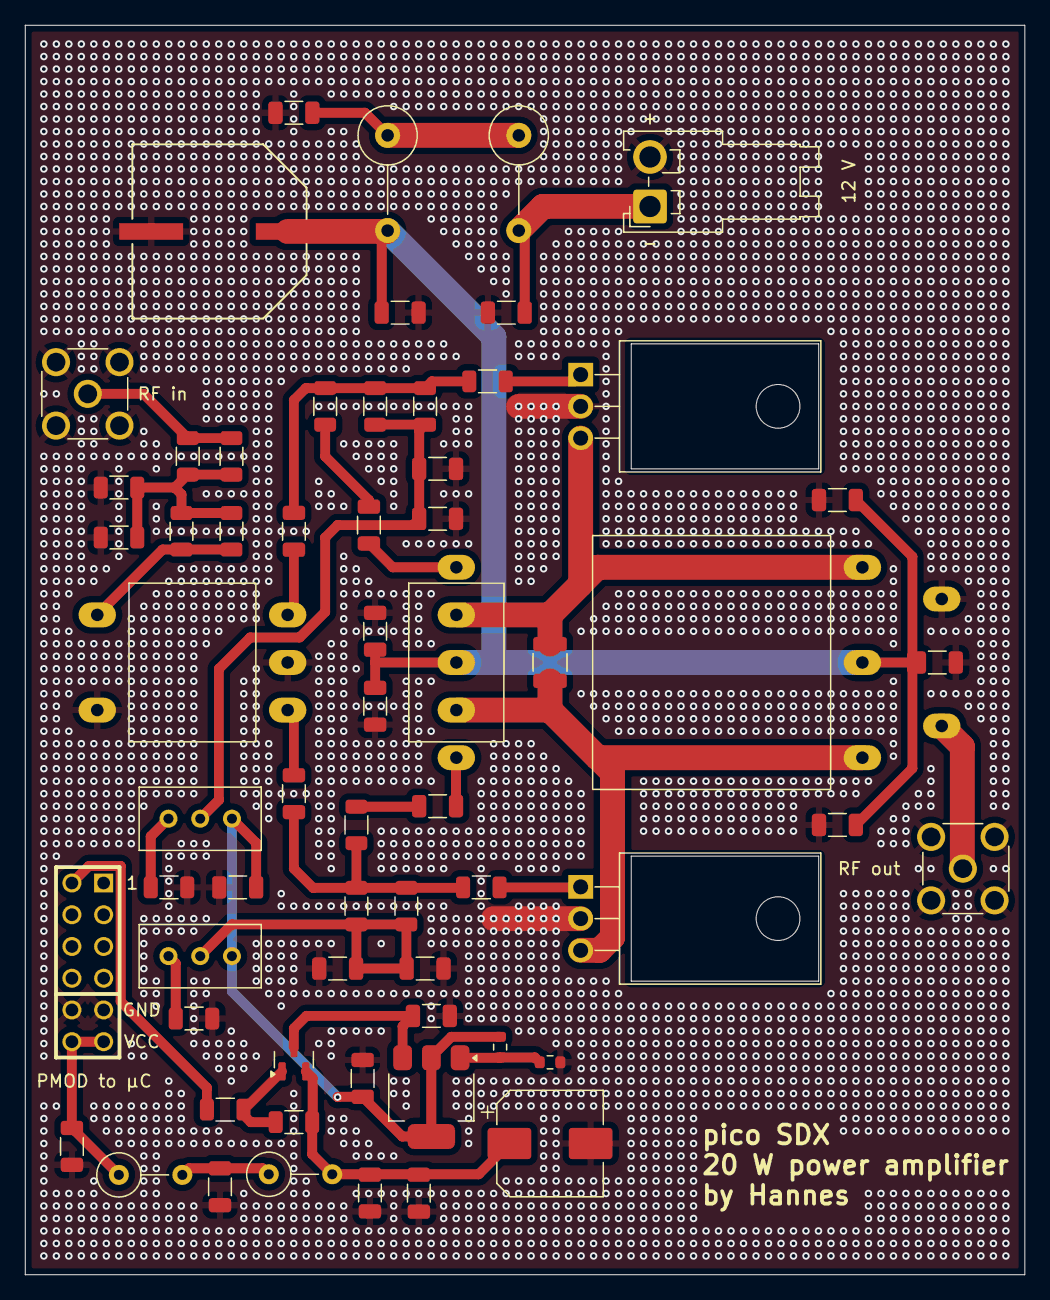
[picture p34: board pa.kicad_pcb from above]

Board: 2 copper layers, 80.0 x 100.0 mm, 63 parts (0 on the bottom side), 32 nets.

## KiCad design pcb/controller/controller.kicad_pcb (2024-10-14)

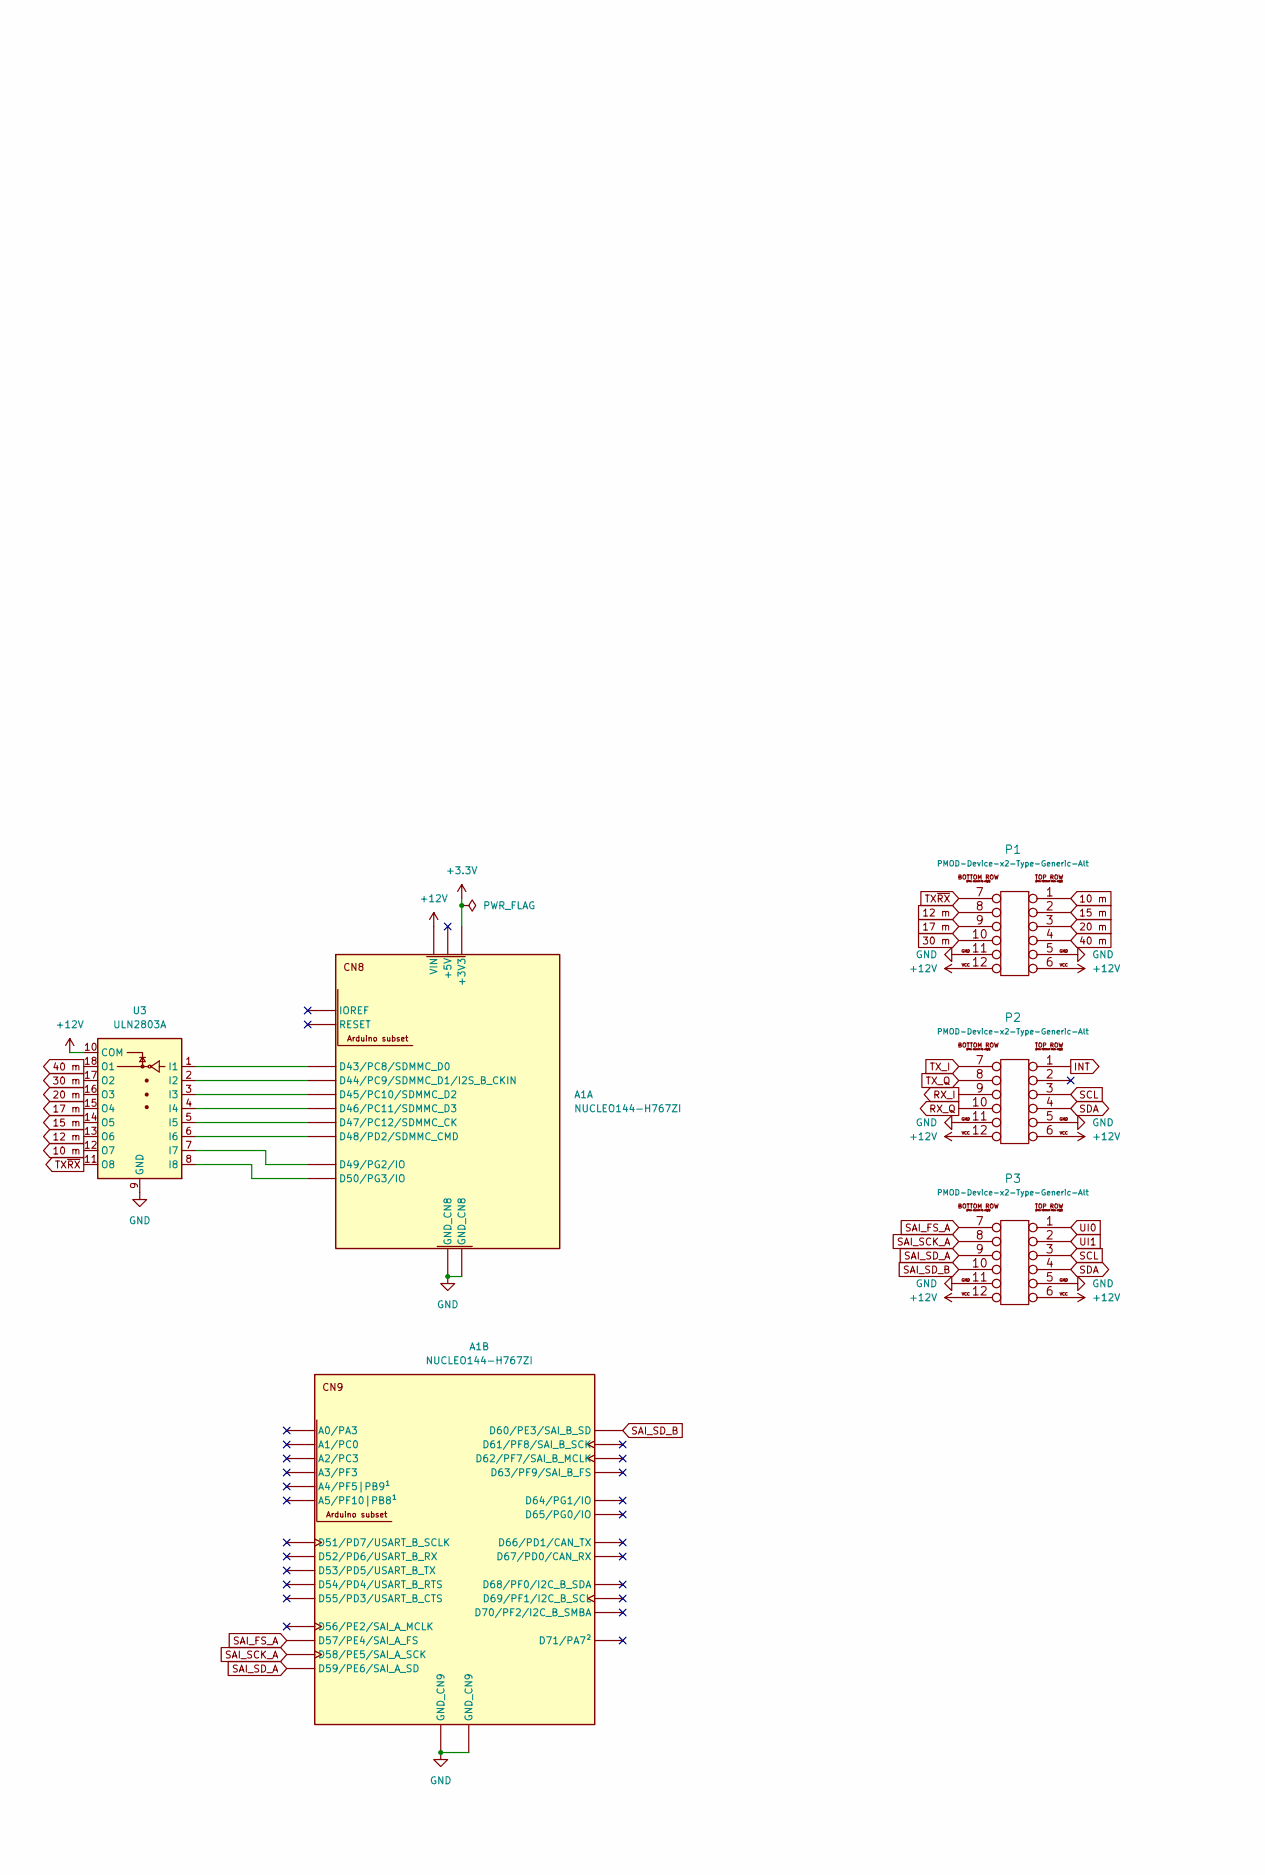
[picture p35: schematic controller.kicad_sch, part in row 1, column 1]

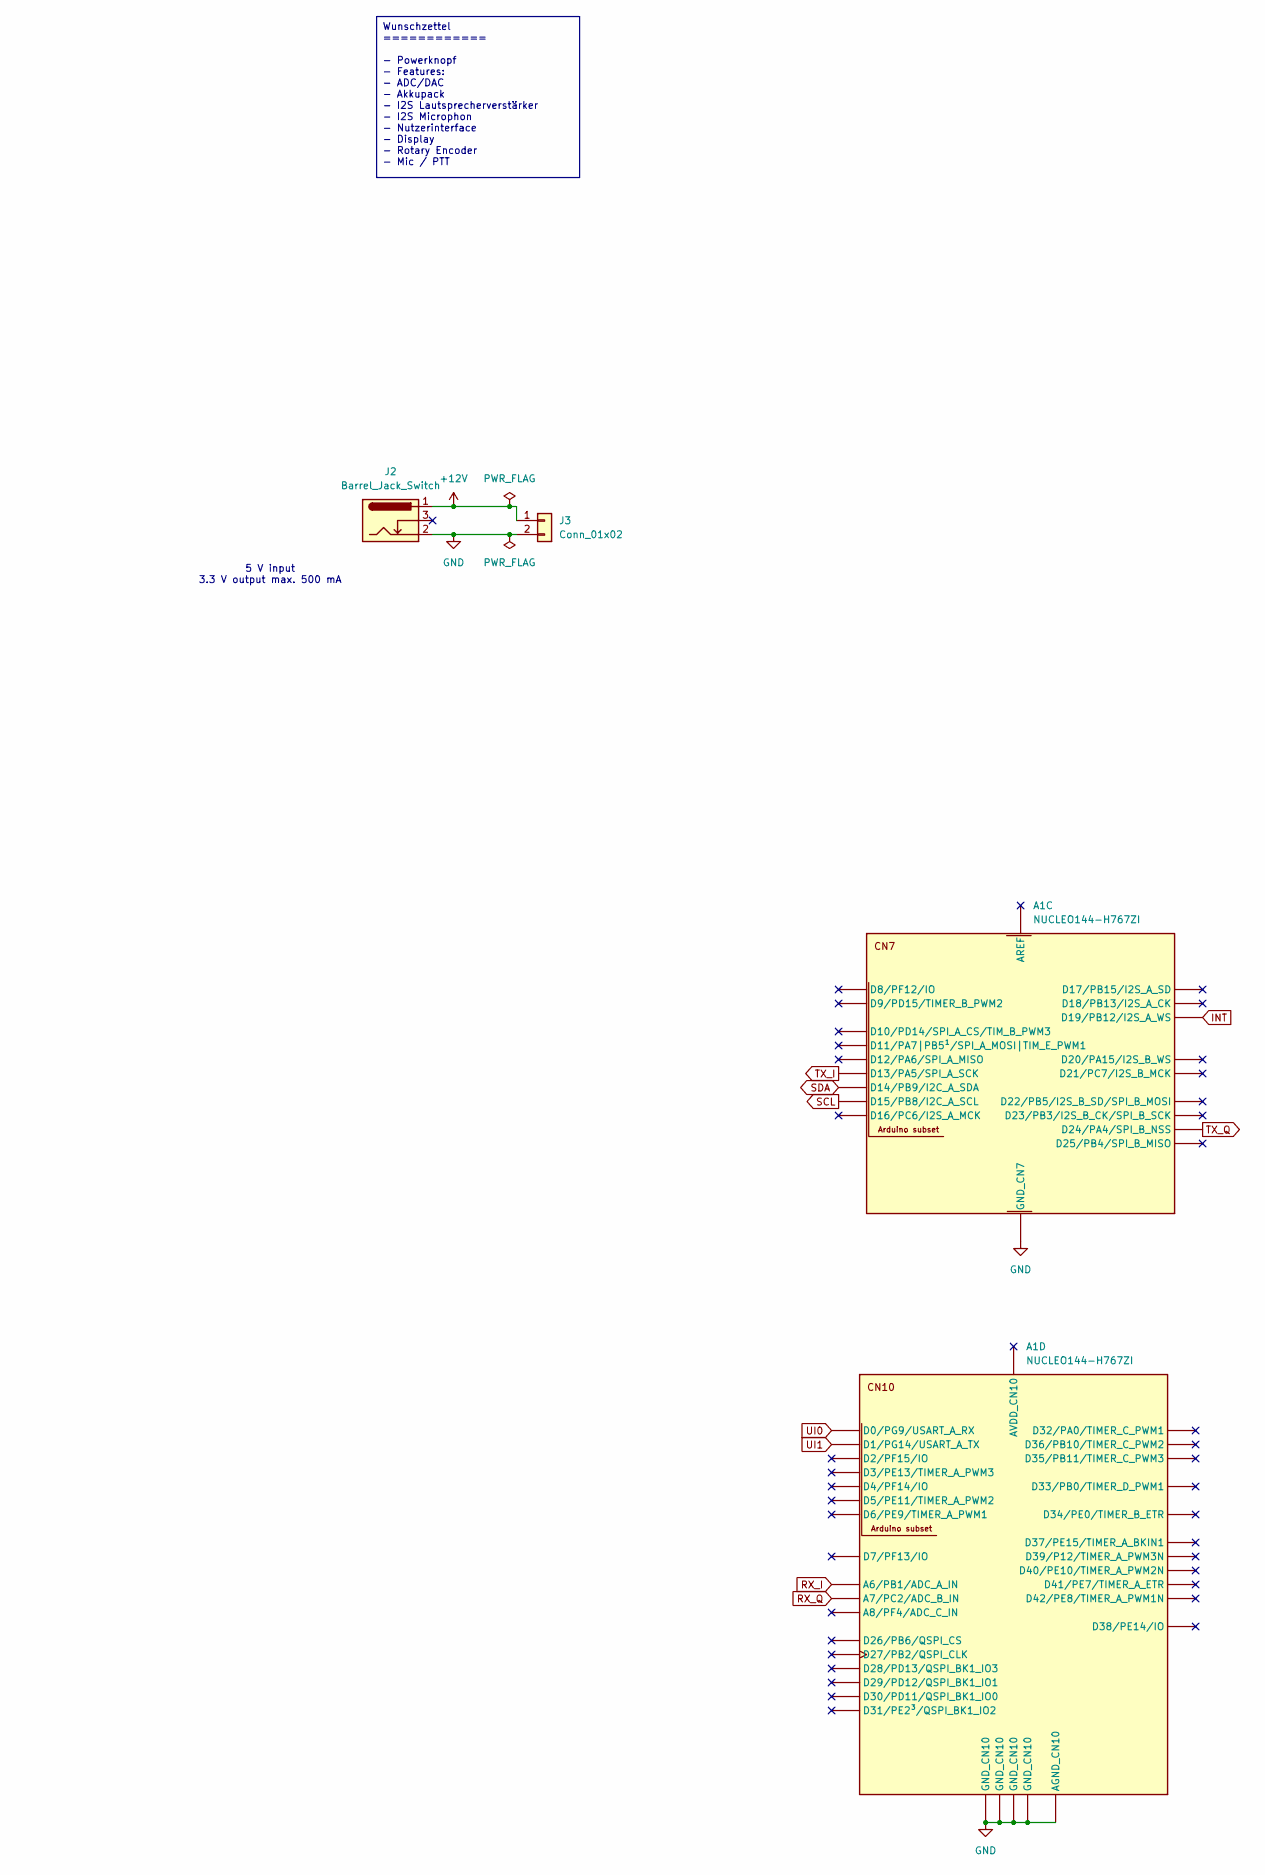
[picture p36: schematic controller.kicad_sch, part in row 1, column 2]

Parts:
A1: NUCLEO144-H767ZI; ST_Zio_Connectors_144_STLink
J2: Barrel_Jack_Switch; BarrelJack_Wuerth_6941xx301002
J3: Conn_01x02; SolderWire-0.75sqmm_1x02_P7mm_D1.25mm_OD3.5mm
P1, P2, P3: PMOD-Device-x2-Type-Generic-Alt; pmod_pin_array_6x2
U3: ULN2803A; SOIC-18W_7.5x11.6mm_P1.27mm

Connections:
10 m: P1.1, U3.12 (O7)
12 m: P1.8, U3.13 (O6)
15 m: P1.2, U3.14 (O5)
17 m: P1.9, U3.15 (O4)
20 m: P1.3, U3.16 (O3)
30 m: P1.10, U3.17 (O2)
40 m: P1.4, U3.18 (O1)
+3.3V: A1.CN8_7 (+3V3)
+12V: A1.CN8_15 (VIN), J2.1, J3.1, P1.6, P1.12, P2.6, P2.12, P3.6, P3.12, U3.10 (COM)
GND: A1.CN7_8 (GND_CN7), A1.CN8_11 (GND_CN8), A1.CN8_13 (GND_CN8), A1.CN9_12 (GND_CN9), A1.CN9_23 (GND_CN9), A1.CN10_3 (AGND_CN10), A1.CN10_5 (GND_CN10), A1.CN10_17 (GND_CN10), A1.CN10_22 (GND_CN10), A1.CN10_27 (GND_CN10), J2.2, J3.2, P1.5, P1.11, P2.5, P2.11, P3.5, P3.11, U3.9 (GND)
INT: A1.CN7_7 (D19/PB12/I2S_A_WS), P2.1
unnamed: A1.CN8_2 (D43/PC8/SDMMC_D0), U3.1 (I1)
unnamed: A1.CN8_4 (D44/PC9/SDMMC_D1/I2S_B_CKIN), U3.2 (I2)
unnamed: A1.CN8_6 (D45/PC10/SDMMC_D2), U3.3 (I3)
unnamed: A1.CN8_8 (D46/PC11/SDMMC_D3), U3.4 (I4)
unnamed: A1.CN8_10 (D47/PC12/SDMMC_CK), U3.5 (I5)
unnamed: A1.CN8_12 (D48/PD2/SDMMC_CMD), U3.6 (I6)
unnamed: A1.CN8_14 (D49/PG2/IO), U3.7 (I7)
unnamed: A1.CN8_16 (D50/PG3/IO), U3.8 (I8)
RX_I: A1.CN10_7 (A6/PB1/ADC_A_IN), P2.9
RX_Q: A1.CN10_9 (A7/PC2/ADC_B_IN), P2.10
SAI_FS_A: A1.CN9_16 (D57/PE4/SAI_A_FS), P3.7
SAI_FS_B: A1.CN9_28 (D63/PF9/SAI_B_FS)
SAI_MCLK_A: A1.CN9_14 (D56/PE2/SAI_A_MCLK)
SAI_MCLK_B: A1.CN9_26 (D62/PF7/SAI_B_MCLK)
SAI_SCK_A: A1.CN9_18 (D58/PE5/SAI_A_SCK), P3.8
SAI_SCK_B: A1.CN9_24 (D61/PF8/SAI_B_SCK)
SAI_SD_A: A1.CN9_20 (D59/PE6/SAI_A_SD), P3.9
SAI_SD_B: A1.CN9_22 (D60/PE3/SAI_B_SD), P3.10
SCL: A1.CN7_2 (D15/PB8/I2C_A_SCL), P2.3, P3.3
SDA: A1.CN7_4 (D14/PB9/I2C_A_SDA), P2.4, P3.4
TX_I: A1.CN7_10 (D13/PA5/SPI_A_SCK), P2.7
TX_Q: A1.CN7_17 (D24/PA4/SPI_B_NSS), P2.8
TX~RX: P1.7, U3.11 (O8)
UI0: A1.CN10_16 (D0/PG9/USART_A_RX), P3.1
UI1: A1.CN10_14 (D1/PG14/USART_A_TX), P3.2

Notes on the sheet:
Wunschzettel ============ - Powerknopf - Features: - ADC/DAC - Akkupack - I2S Lautsprecherverstärker - I2S Microphon - Nutzerinterface - Display - Rotary Encoder - Mic / PTT
5 V input 3.3 V output max. 500 mA


Board: 2 copper layers, 160.0 x 100.0 mm, 7 parts (0 on the bottom side), 31 nets.

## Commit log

2024-02-10 add oscillator, upmixer and downmixer. power WIP
    [Oscillator.kicad_sch, downconverter.kicad_sch, pico-sdx.kicad_pcb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]
2024-02-11 update clock module footprint
    [pico-sdx.kicad_pcb]
2024-02-11 add documentation and RaspberryPi Pico
    [downconverter.kicad_sch, pico-sdx.kicad_pcb, pico-sdx.kicad_sch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]
2024-03-05 routed with filter relays without PA
    [PA.kicad_sch, bpf.kicad_sch, buffer.kicad_sch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]
2024-03-22 add active lowpass filter in upconverter branch
    [pico-sdx.kicad_pcb, upconverter.kicad_sch]
2024-04-21 modular design
    [Oscillator.kicad_sch, downconverter.kicad_sch, pico-sdx.kicad_pcb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]
2024-06-18 mixer routed
    [buffer.kicad_sch, downconverter.kicad_sch, pico-sdx.kicad_pcb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]
2024-06-21 clean up
    [pico-sdx.kicad_pcb]
2024-06-21 add bandpass filter board
    [bandpass.kicad_pcb, bandpass.kicad_sch, bpf.kicad_sch]
2024-06-21 add mixer board
    [buffer.kicad_sch, downconverter.kicad_sch, mixer.kicad_pcb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]
2024-08-27 add PA
    [pa.kicad_pcb, pa.kicad_sch]
2024-08-27 add microcontroller board
    [controller.kicad_pcb, controller.kicad_sch]
2024-08-27 remove USB HS PHY
    [controller.kicad_pcb, controller.kicad_sch]
2024-08-27 use lt1117 as linear voltage regulator
    [mixer.kicad_pcb, mixer.kicad_sch]
2024-08-27 replace 7806 by 1117
    [pa.kicad_pcb, pa.kicad_sch]
2024-08-27 replace RF connectors, add missing silkscreen text
    [bandpass.kicad_pcb, bandpass.kicad_sch, controller.kicad_pcb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]
2024-10-14 use ZIO footprint for Nucleo
    [controller.kicad_pcb, controller.kicad_sch]
2024-10-14 add gerber parameters for jlcpcb
    [controller.kicad_pcb]
2024-10-14 remove external symbol and footprint libraries
    [controller.kicad_pcb, controller.kicad_sch]
2024-10-14 add gerber export settings and get drc-clean
    [buffer.kicad_sch, mixer.kicad_pcb, mixer.kicad_sch]
2024-10-14 drc clean
    [bandpass.kicad_pcb, bandpass.kicad_sch, bpf.kicad_sch]
2024-10-29 add README.md from external repository
    [BOM.ods, bandpass.kicad_pcb, bandpass.kicad_sch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]
